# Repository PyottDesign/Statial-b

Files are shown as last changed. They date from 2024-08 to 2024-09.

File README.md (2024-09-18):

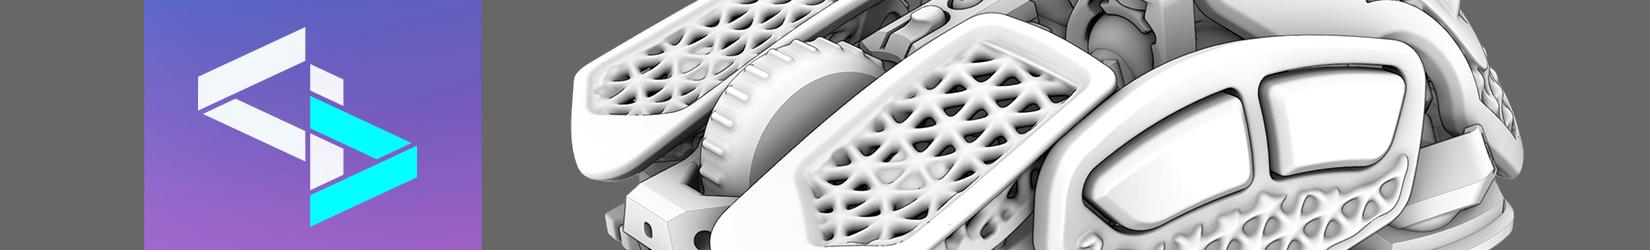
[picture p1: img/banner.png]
Statial.b Title Banner


# Statial.b Adjustable Mouse
_Modern grip styles have grown out of players adapting to standardized mouse shapes.<br/>
The Statial.b lets new mouse shapes grow from grip styles._

The Statial.b is an open source DIY mouse design. This concept has adjustable surfaces that can be moved and locked in position to create a wide range of ergonomics for any grip style. Files for ambidextrous builds are included in the STL.zip "extras" folder.

Knowledge of 3D printing, basic electronics & soldering skills as well as the ability to upload the supplied code to an Arduino are needed for this build. The design is based around a 16,000 DPI optical sensor in the [PMW3389](https://www.tindie.com/products/citizenjoe/pmw3389-motion-sensor/) and driven by an Arduino compatible [Pro Micro](https://deskthority.net/wiki/Arduino_Pro_Micro) controller.

This is a fairly complex project. I tried to cover all the assembly details in the in the [instructions PDF](statial-b_instructions_v01-00.pdf) and on the [YouTube instructions](https://youtu.be/HTKbrcy7GT0), but some problem solving skills are still going to be required.

The finished design is a functioning prototype that requires a lot of adjusting to get it dialed in and is more fragile than a normal commercially produced product. It’s also a heavy mouse weighing up to a hefty 130 grams (depending on components used). All that said, it works great and is super fun to use. There’s really nothing else like it out there if you’re looking to explore mouse ergonomics.

All 3D printed parts need to be made in a “Tough” or “ABS like” resin material. Resin print color is up to you.<br/> ***This project requires resin printed parts. 
It (probably) won't work if parts are 3D printed with an FDM printer.***

Current cost estimate is around $200 for the build materials (that's in 2024 US dollar bucks, not including tools). This is just a rough guess so you have an idea of what you’re getting into.

Please check [Statial.b Youtube build](https://youtu.be/HTKbrcy7GT0) and the [Statial.b Instructions PDF](statial-b_instructions_v01-00.pdf) for more info on this project.

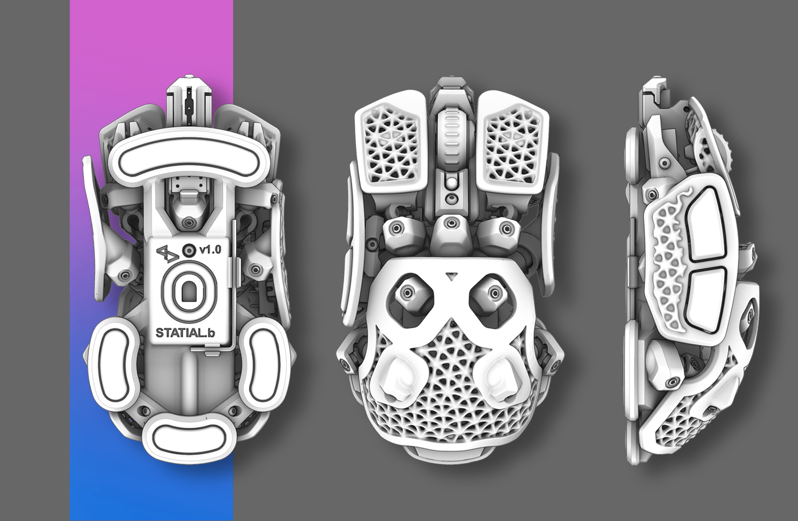
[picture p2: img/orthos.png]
Statial.b Orthos

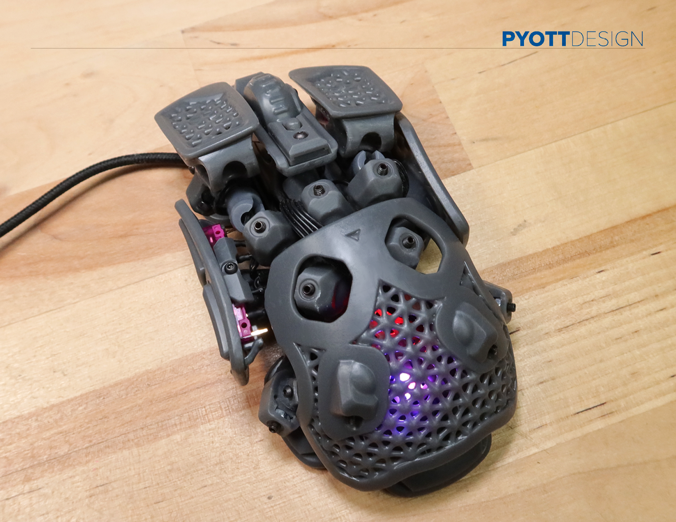
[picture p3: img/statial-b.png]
Statial.b

<br/><br/>

# Code Background
* The Statial-b Arduino Sketch is modified from the [Ben Makes Everything PMW3389 Mouse](https://github.com/BenMakesEverything/PMW3389_Mouse)
* Which is based on [Dkao's Trackball Project](https://github.com/dkao/Kensington_Expert_Mouse_PMW3389_Arduino)
* That uses source code from [MrJohnk PMW3389](https://github.com/mrjohnk/PMW3389DM)
<br/><br/>

# Parts
Full BOM with source links can be found in the [Statial.b Instructions PDF](statial-b_instructions_v01-00.pdf).

* ~170 mL of [Tough](https://formlabs.com/store/materials/tough-2000-resin/) or [ABS Like](https://store.anycubic.com/products/abs-like-resin-pro-2) resin
* [PMW3389 Optical Sensor](https://www.tindie.com/products/citizenjoe/pmw3389-motion-sensor/)
* [Pro Micro (5 Volt/16 MHz)](https://deskthority.net/wiki/Arduino_Pro_Micro)
* [Custom Bridge Board & Middle Routing Board PCB](https://jlcpcb.com/?from=PyottDesign)
* M2 button head screws & M2.5 set screws
* M2 and M2.5 nuts
* 1/8" diameter aluminum tube stock
* Mouse Glides for Logitech G-Pro
* 2.0mm pitch PH type end connectors & right angle through hole board connectors
* (5) Mouse switches
* Push button momentary switch, 6mm x 6mm x 4.5mm
* 2.54mm headers, surface mount gull wing, cut to length
* [TTC Rotary Encoder](https://a.co/d/5zIg8kU)
* [NeoPixel 5050 RGB LED](https://www.adafruit.com/product/1655)
* ~6' Micro USB cable or Mouse cable w/ micro USB port connector component 
* 28 Ga. 6 conductor silicone ribbon wire (or similar)
* Soldering Iron, Multi-meter, [PH Crimping tool](https://a.co/d/hdylA0W) and other misc. tools

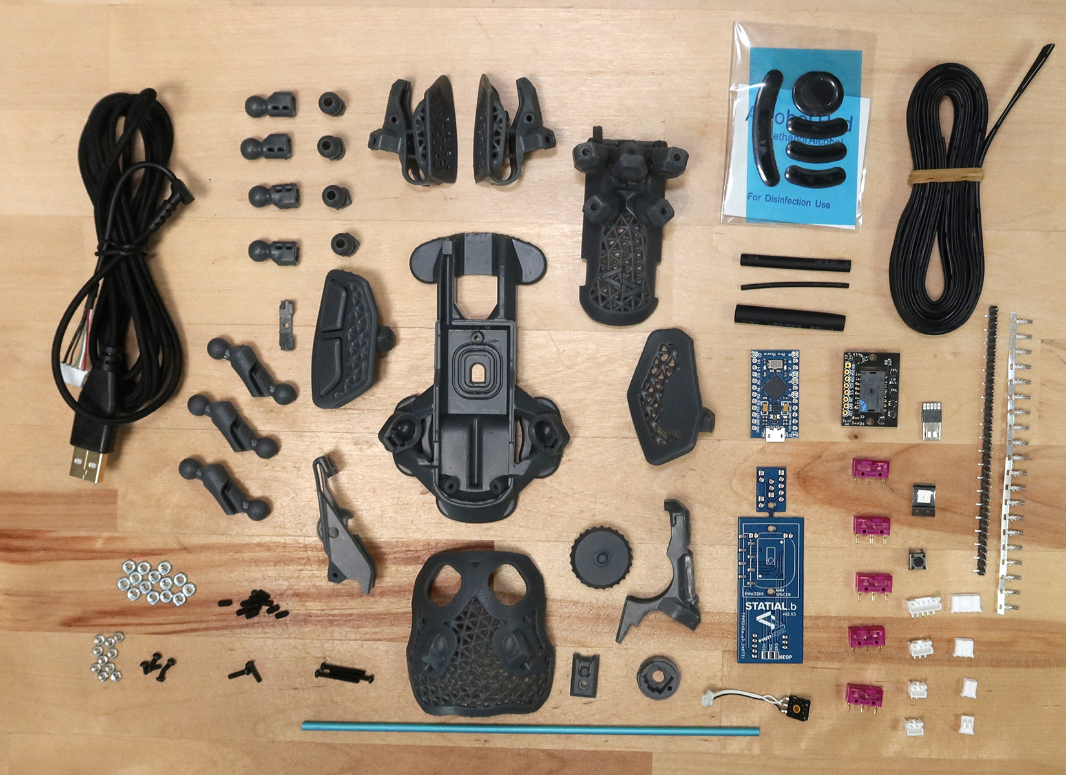
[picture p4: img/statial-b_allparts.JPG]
Statial.b All Parts

<br/><br/>

# Configurations
Below are some common grip type configurations for the Statial.b as starting points for further adjustment. Mouse ergronomics are extreamly sensitive. A 1mm or 1 degree adjustment can take an uncomfortable setup to a great one (and vice versa). When using the Statial.b, try and think about what feels right and what feels off in your grip and make micro adjstments to single surfaces only until it's dialed in. 

### VARIABLE PALM
When fully collapsed the Statial.b is slightly smaller than a normal high performance mouse. Surfaces can be moved out significantly for larger hands.
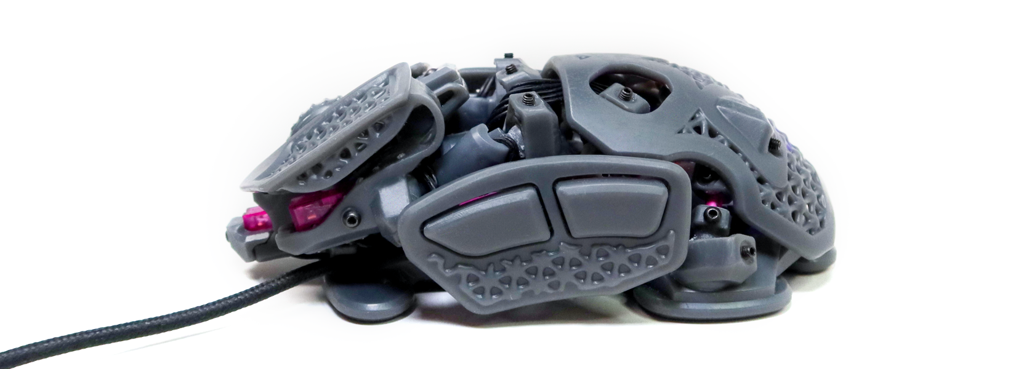
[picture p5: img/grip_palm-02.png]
Statial.b palm grip

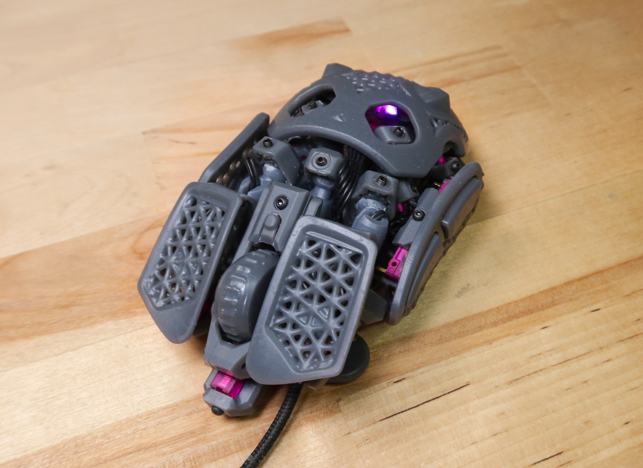
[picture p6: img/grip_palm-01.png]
Statial.b palm grip


### STUBNOSE CLAW
Unlike a normal mouse, the buttons on the Statial.b can pitch forward for different grip types. This allows claw grip users to position buttons perpendicular to the pressing motion.
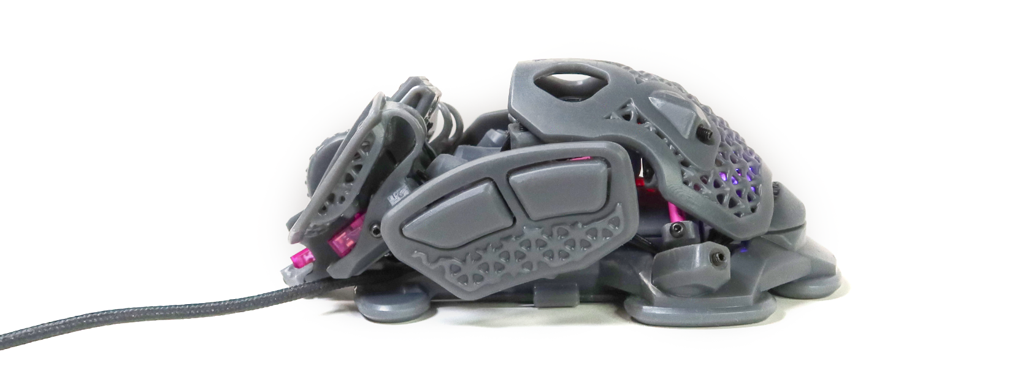
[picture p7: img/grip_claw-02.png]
Statial.b claw grip

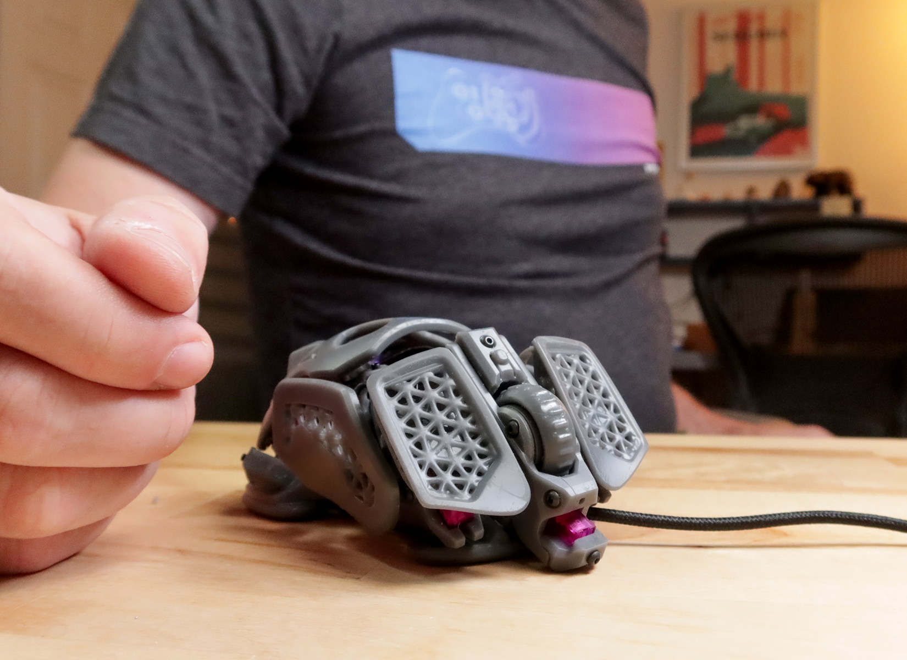
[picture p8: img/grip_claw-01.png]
Statial.b claw grip


### BACKLESS FINGER
Surfaces can be configured to experiment with alternate grip methods. For example; finger grip users can remove back surface entirely.
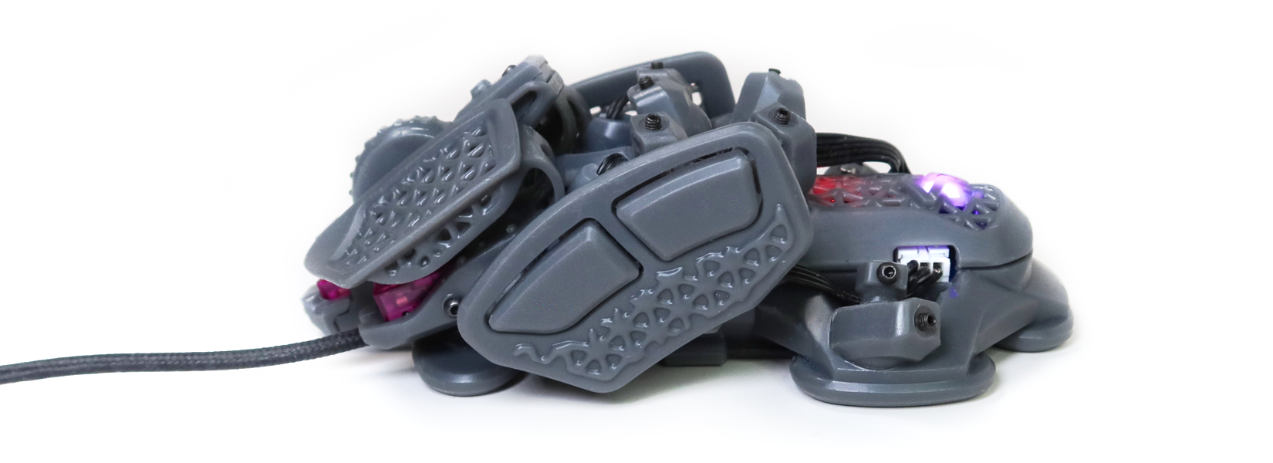
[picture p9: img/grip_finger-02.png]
Statial.b finger grip

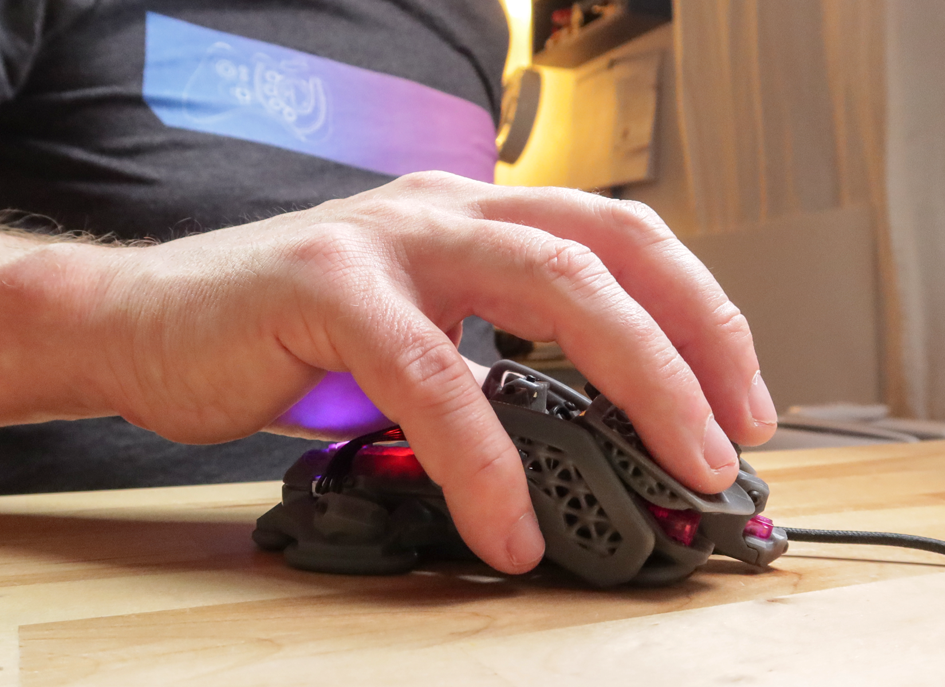
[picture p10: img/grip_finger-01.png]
Statial.b finger grip


### ERGO VERTICAL
Surfaces can be configured to +40° angle to mimic the fit of a vertical mouse. Fixed ends of rear surface arms can be extended or longer sections of tube can be cut for even steeper angles. 
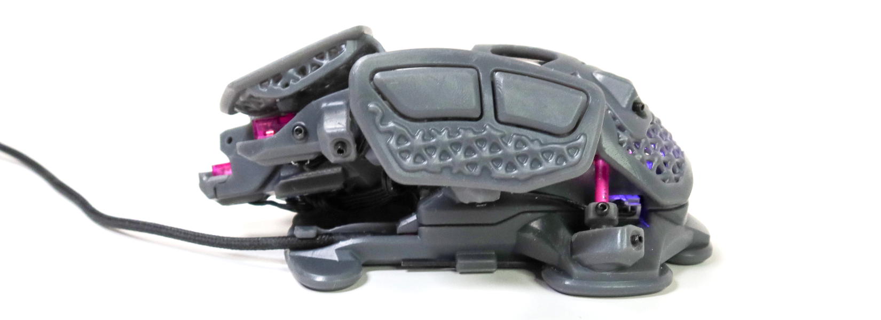
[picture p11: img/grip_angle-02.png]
Statial.b angle grip

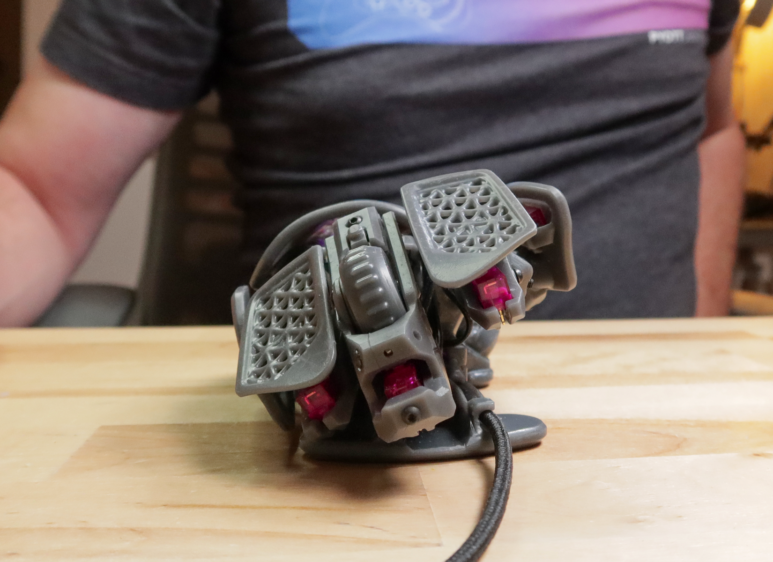
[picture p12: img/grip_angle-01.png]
Statial.b angle grip

<br/><br/>

# Instructions
For complete instructions, please download the [Statial.b Instructions PDF](https://github.com/PyottDesign/Statial-b/statial-b_instructions_v01-00.pdf).

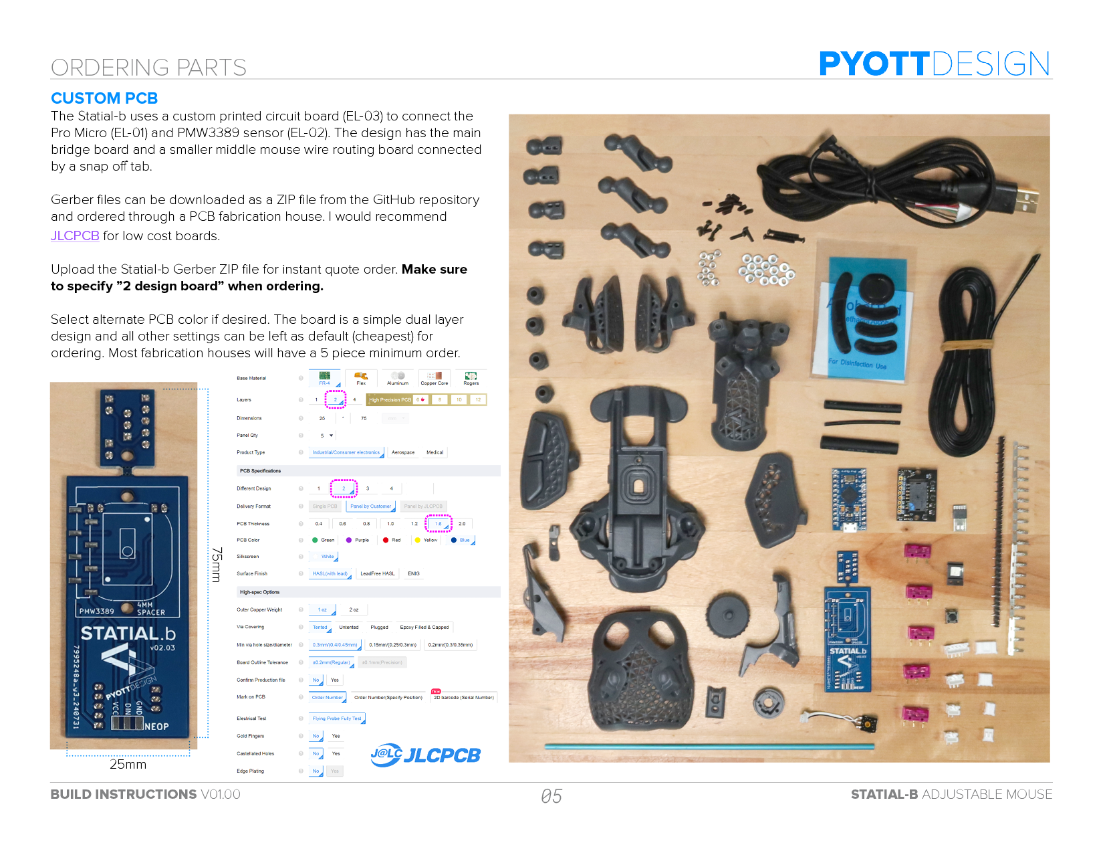
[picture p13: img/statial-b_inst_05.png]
Statial.b Instruction Manual


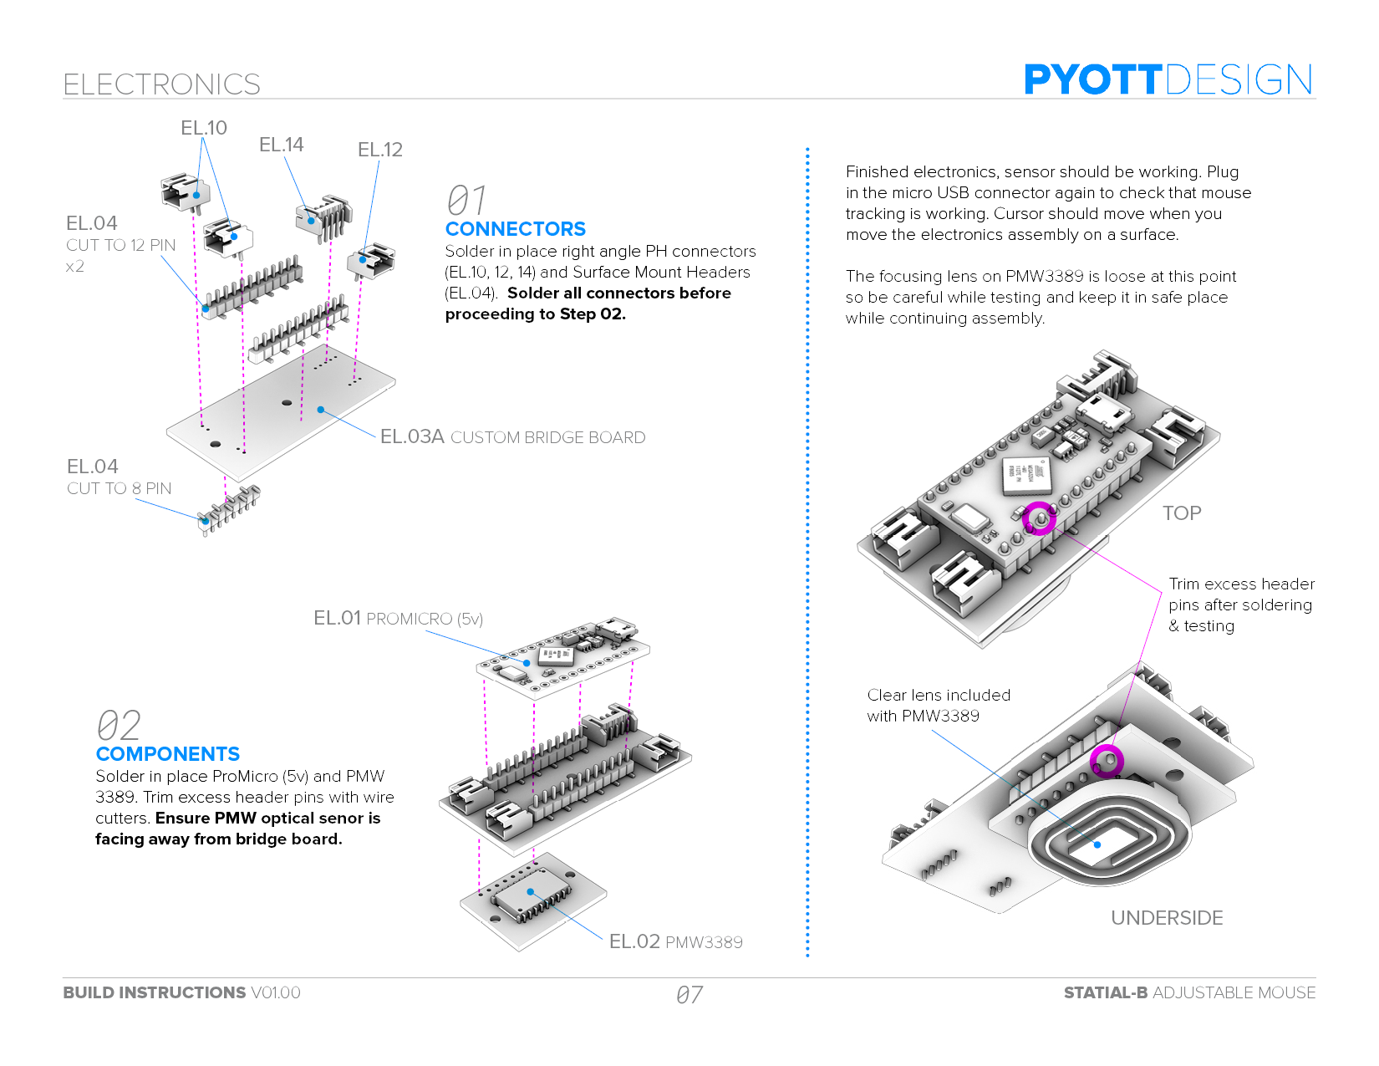
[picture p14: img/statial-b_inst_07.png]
Statial.b Instruction Manual


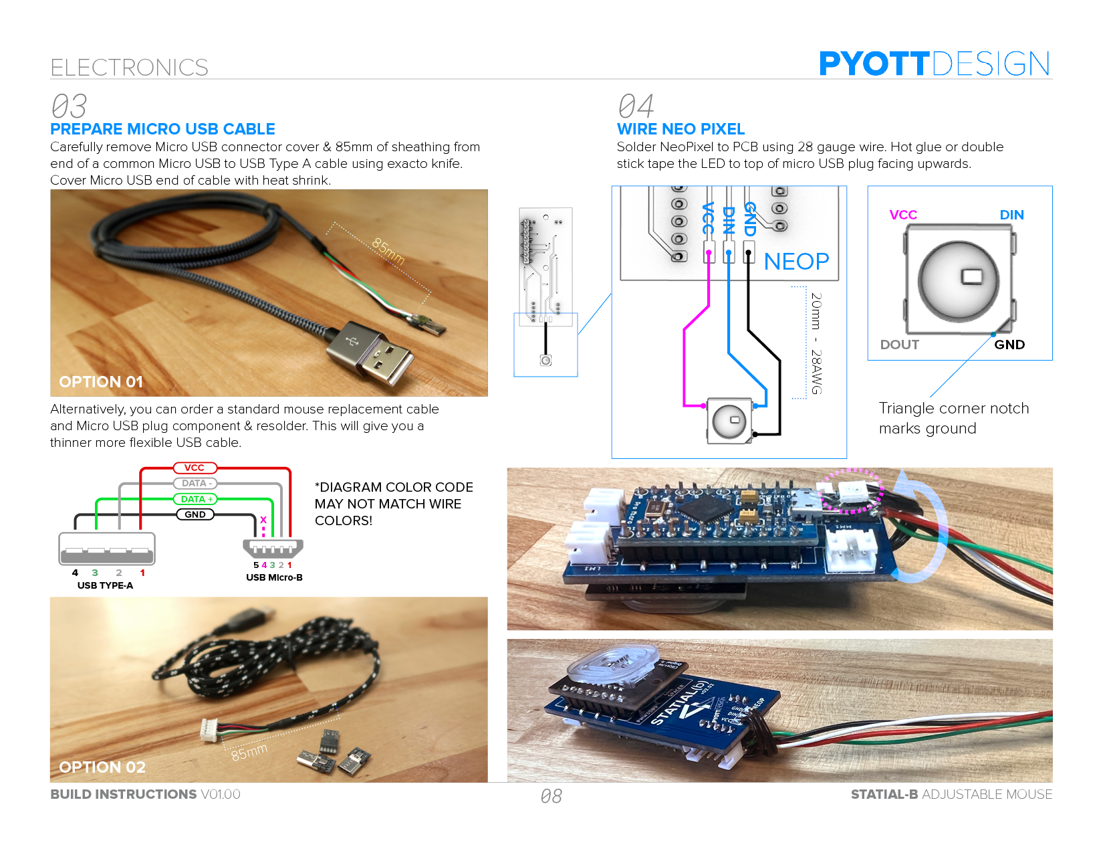
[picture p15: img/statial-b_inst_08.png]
Statial.b Instruction Manual


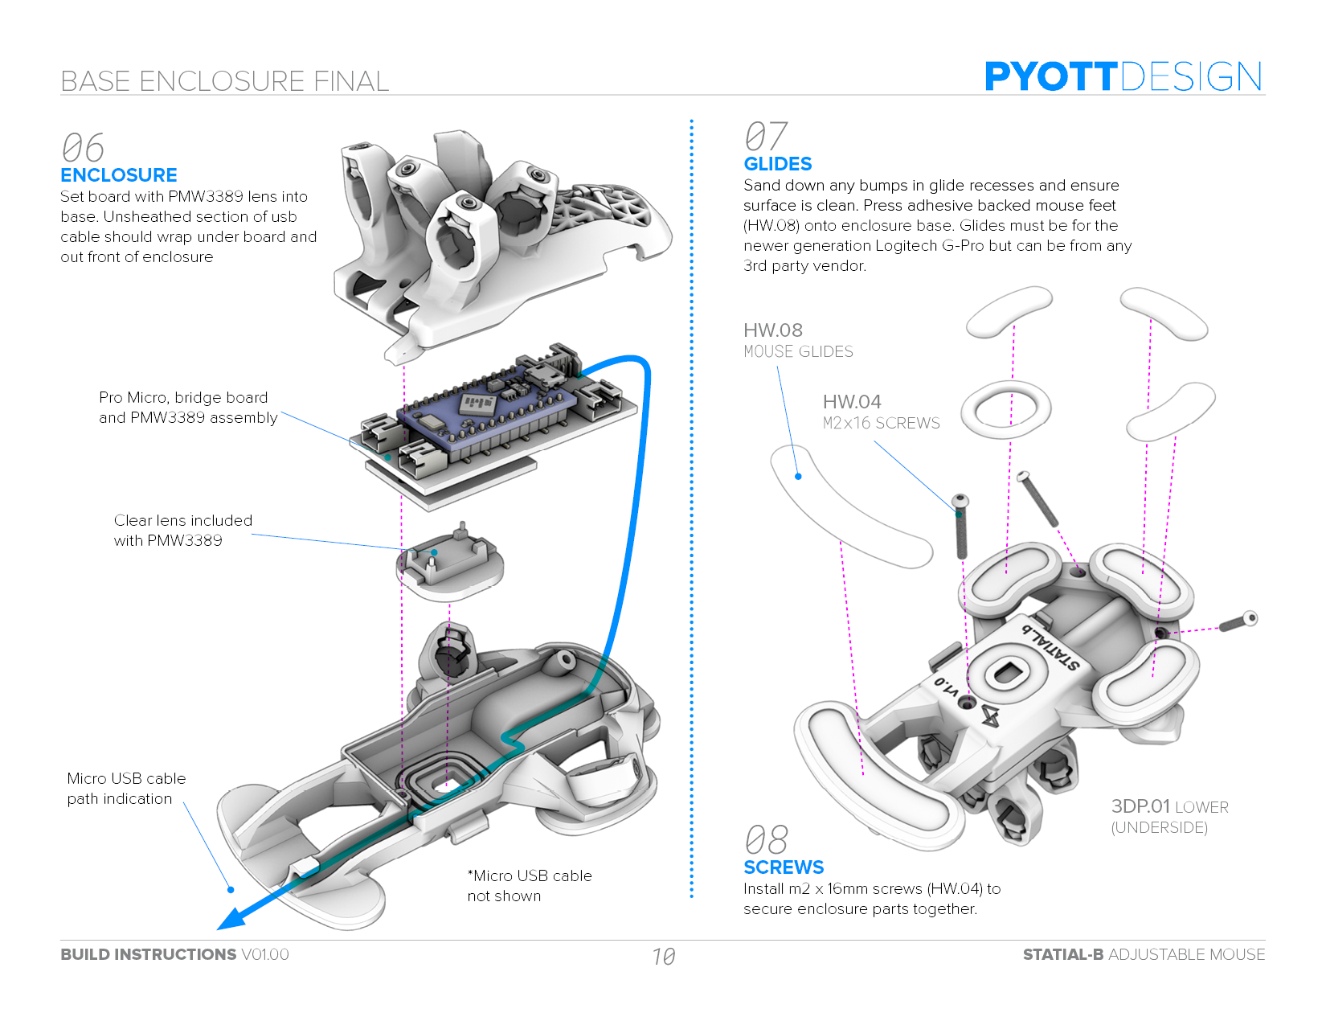
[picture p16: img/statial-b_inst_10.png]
Statial.b Instruction Manual


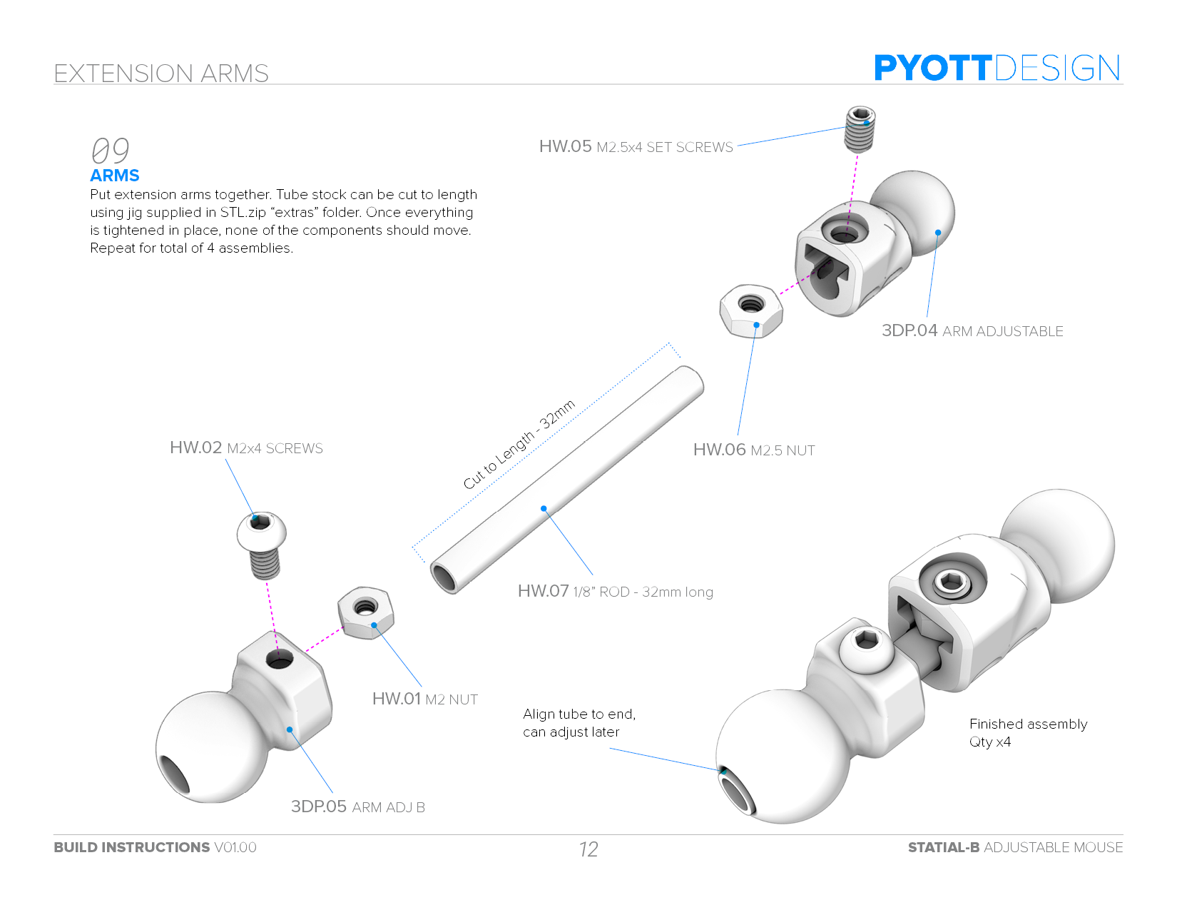
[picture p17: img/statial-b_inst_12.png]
Statial.b Instruction Manual


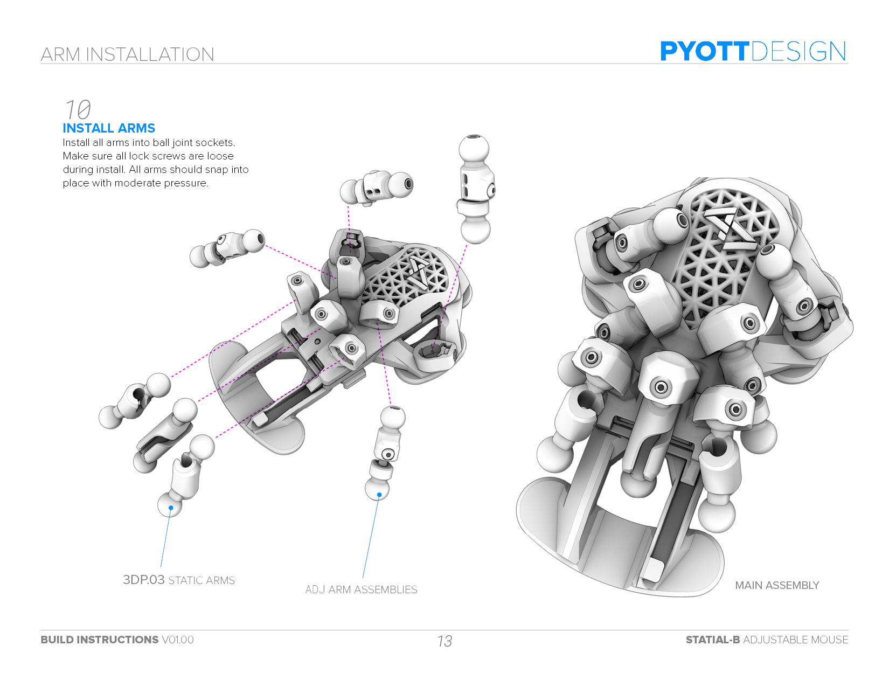
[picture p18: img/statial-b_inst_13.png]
Statial.b Instruction Manual


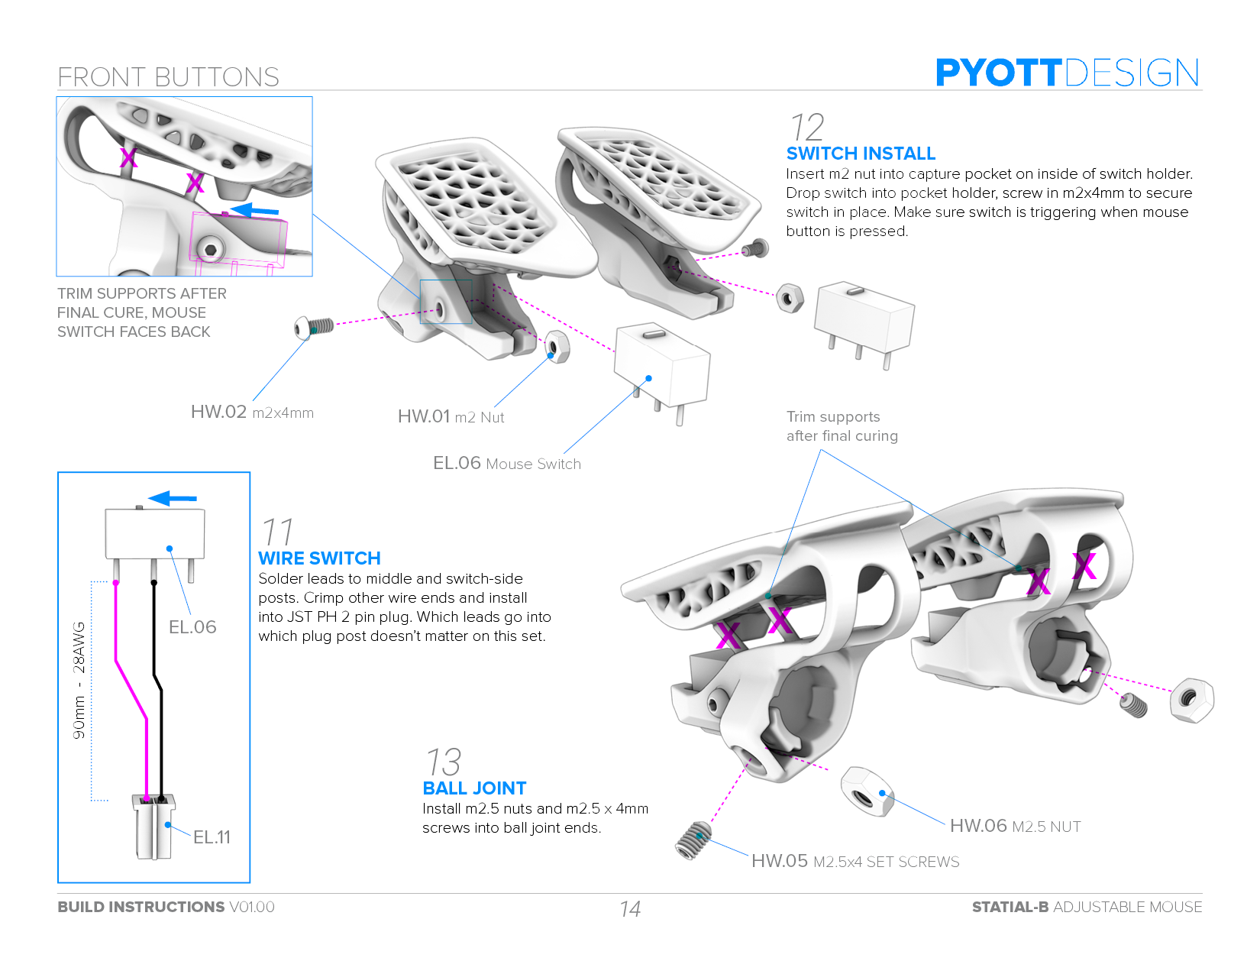
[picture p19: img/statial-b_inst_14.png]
Statial.b Instruction Manual


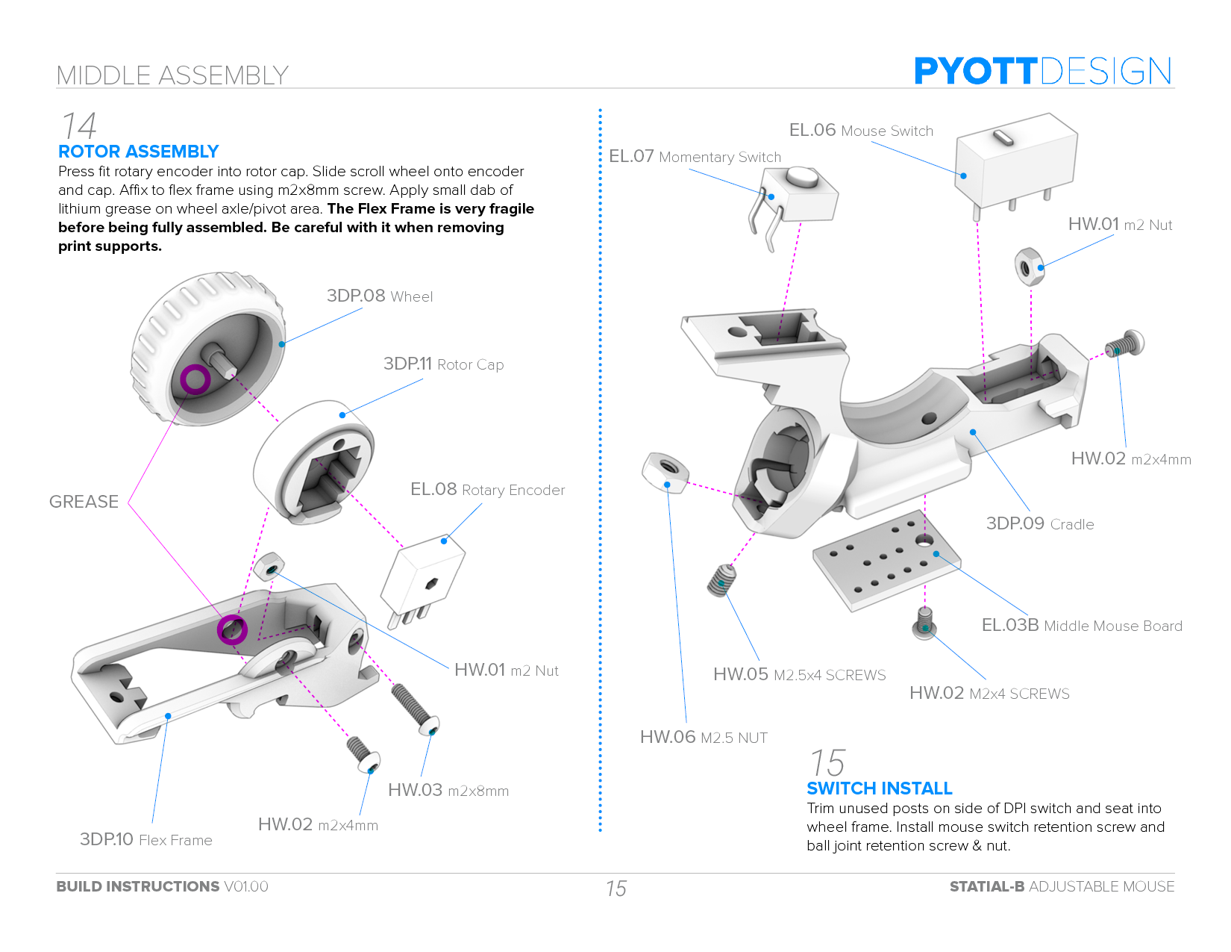
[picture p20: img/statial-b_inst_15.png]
Statial.b Instruction Manual


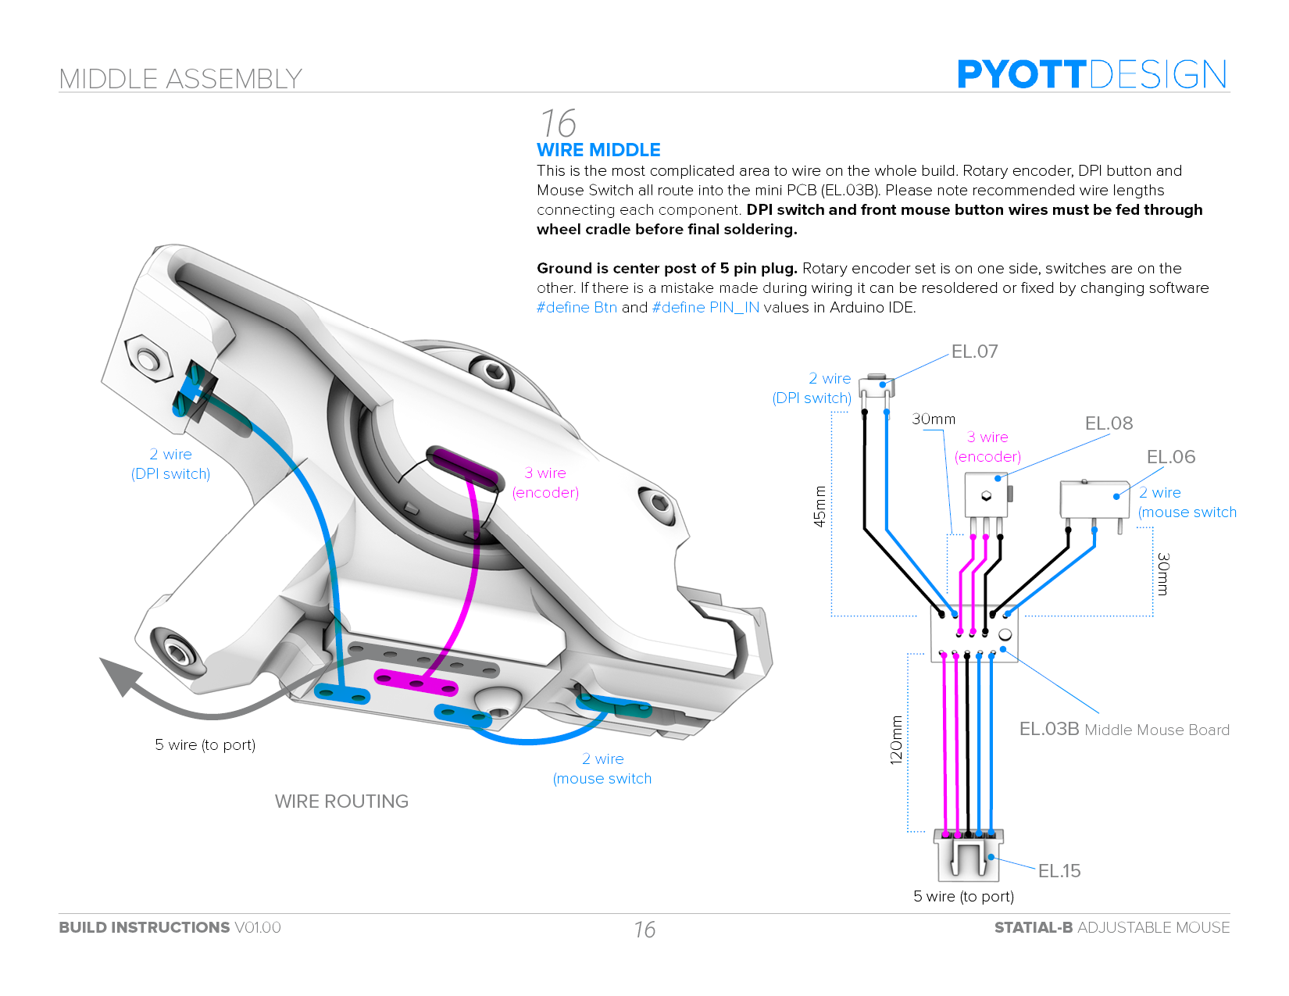
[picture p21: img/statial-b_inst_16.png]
Statial.b Instruction Manual


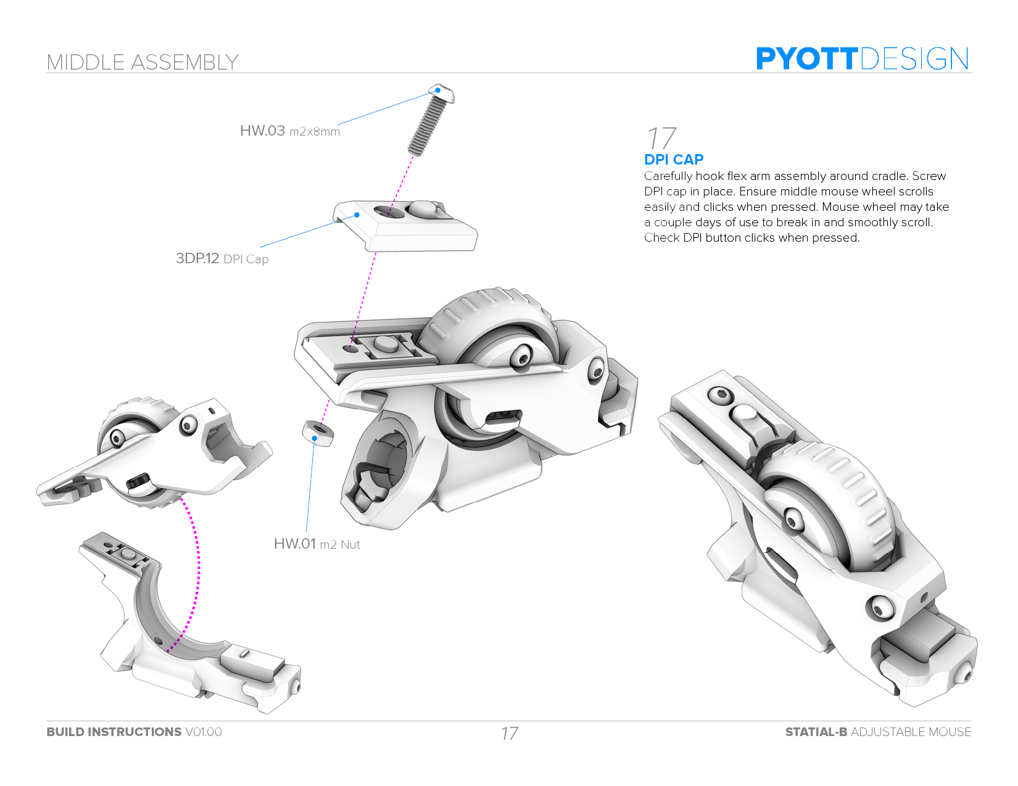
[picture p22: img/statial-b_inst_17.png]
Statial.b Instruction Manual


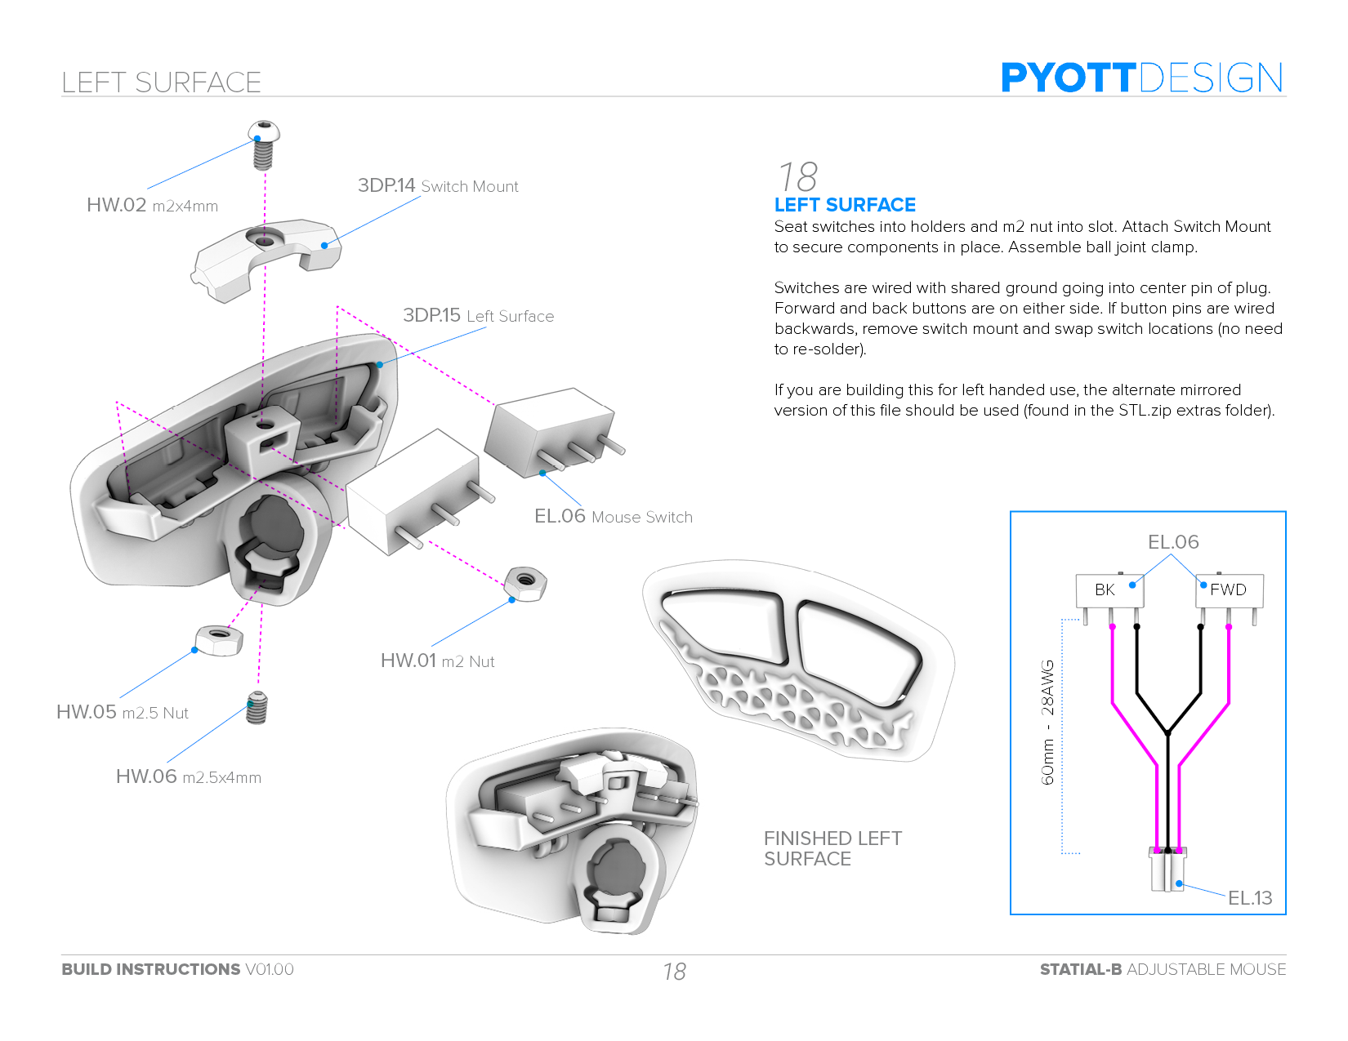
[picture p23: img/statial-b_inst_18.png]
Statial.b Instruction Manual


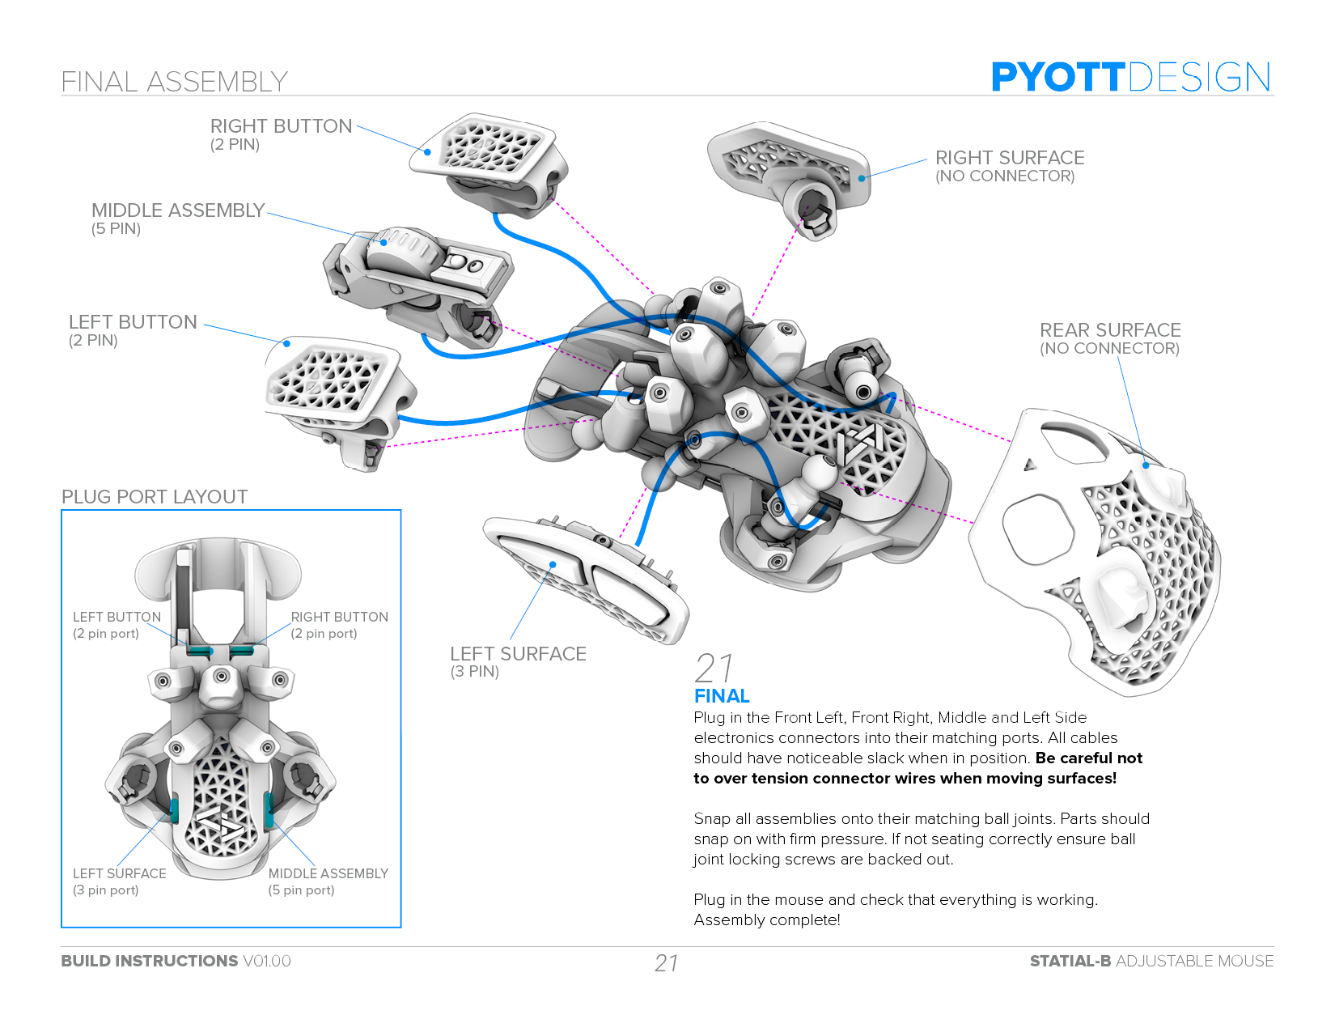
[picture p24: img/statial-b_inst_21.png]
Statial.b Instruction Manual


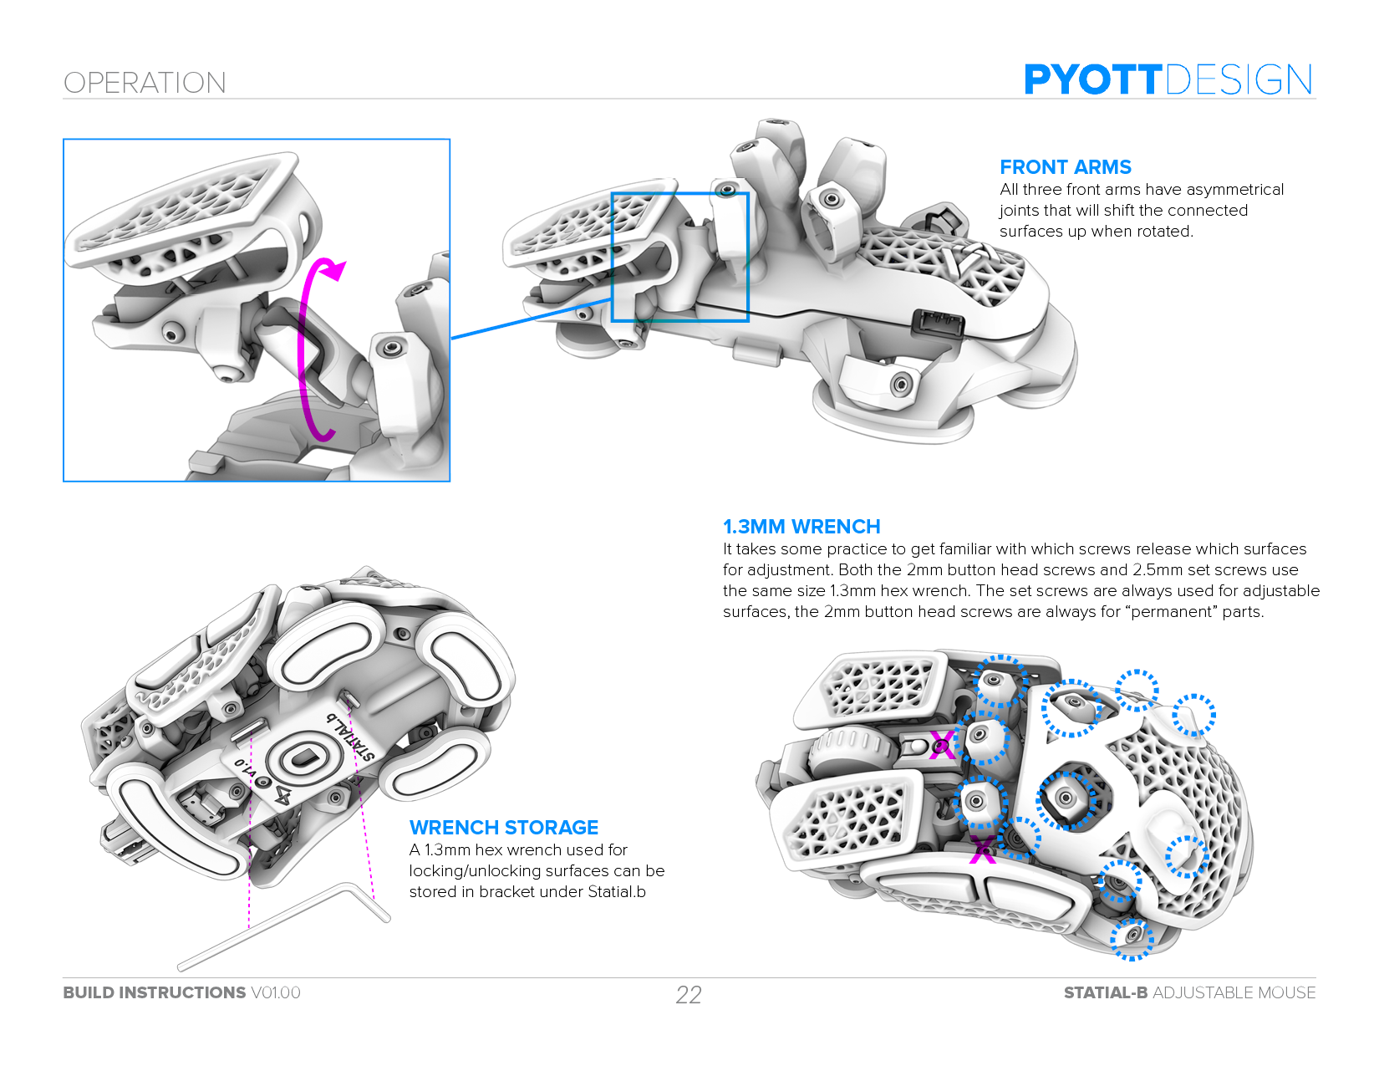
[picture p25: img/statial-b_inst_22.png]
Statial.b Instruction Manual


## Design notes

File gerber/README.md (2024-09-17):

# NOTES
Download the Statial.b Gerber file by selecting the Statial-b_v02-03_Gerber.zip link listed above.<br/>
Then select the "download raw file" icon in upper right.<br/><br/>

From there go to [JLCPCB](https://jlcpcb.com/?from=PyottDesign) and upload the Statial Gerber zip file by selecting the "add gerber file" button. The Gerber file contains both the main board and the middle mouse button sub-board connected by break away tabs so **make sure to set "Different Design" to 2.** Select your prefered board color (or leave default green). All other settings can be left as a default 2-layer 1.6mm thick.

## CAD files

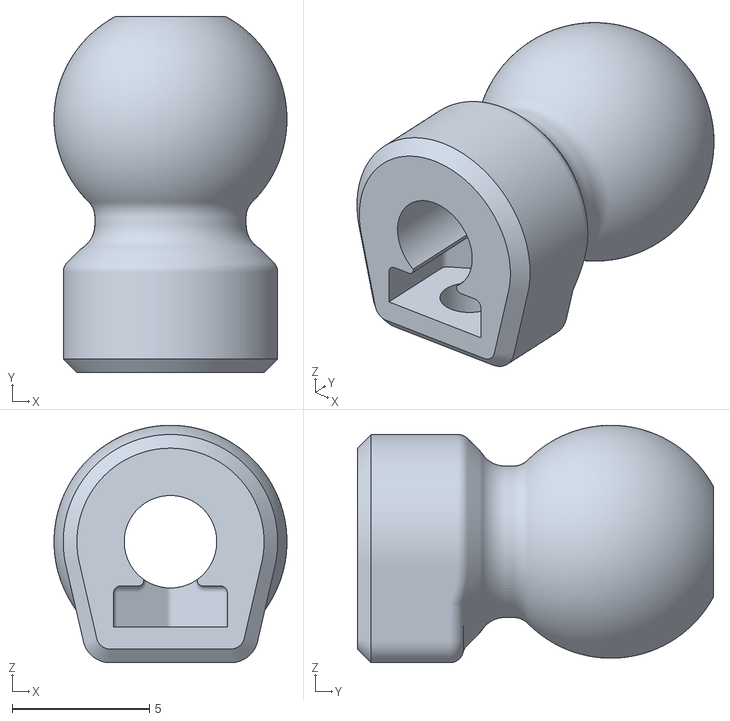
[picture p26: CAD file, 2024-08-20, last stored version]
3d_printables/stl/arm-adj-B_SBv10A01_qty-04.stl
8.50 x 13.0 x 8.66

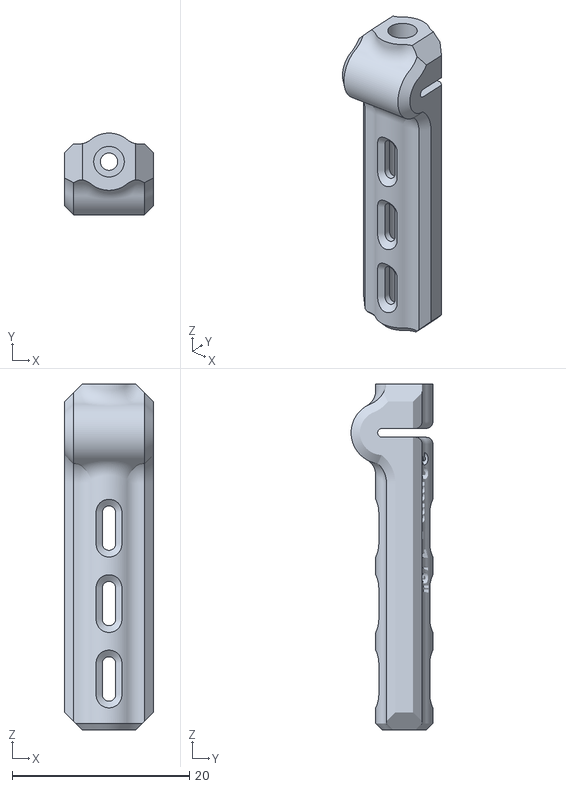
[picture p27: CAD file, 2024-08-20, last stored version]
3d_printables/stl/extras/cutting-jig_32mm.stl
10.0 x 9.22 x 39.0

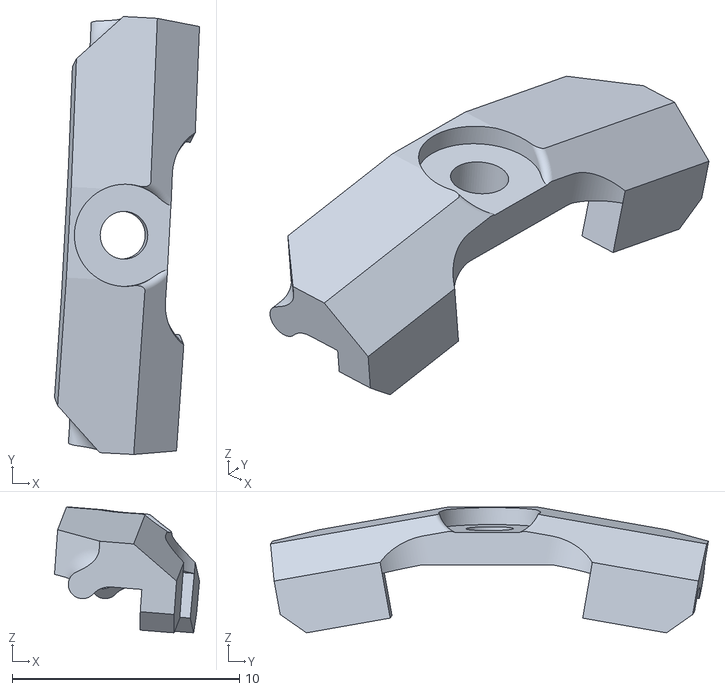
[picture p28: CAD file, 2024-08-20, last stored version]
3d_printables/stl/side-switch_SBv10A01_qty-01.stl
6.39 x 19.3 x 5.53

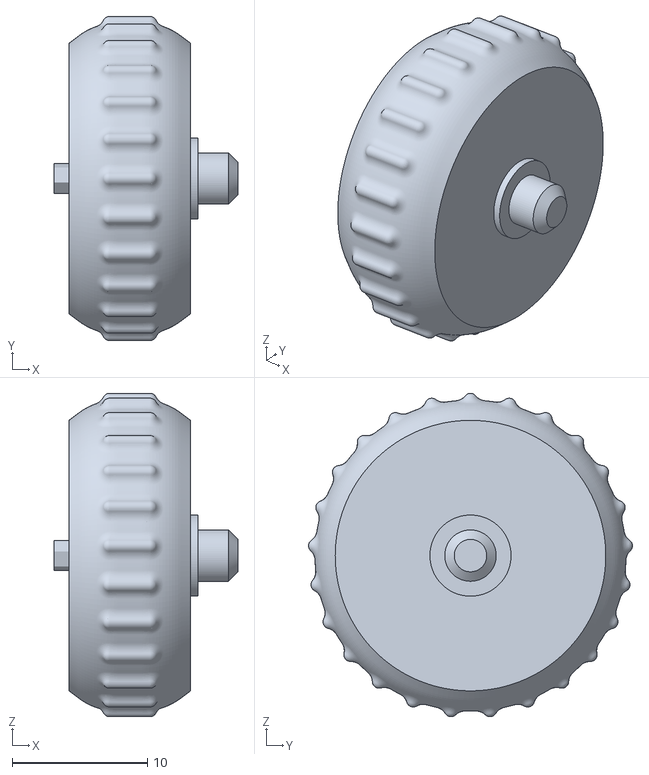
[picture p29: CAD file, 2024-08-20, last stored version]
3d_printables/stl/mid-wheel_SBv10A01_qty-01.stl
13.6 x 24.0 x 23.9

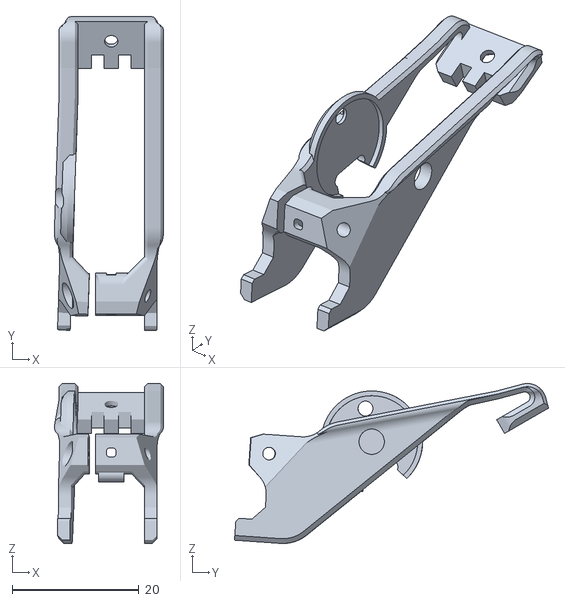
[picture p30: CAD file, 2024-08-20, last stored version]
3d_printables/stl/mid-flex_SBv10A01_qty-01.stl
17.2 x 49.5 x 25.2

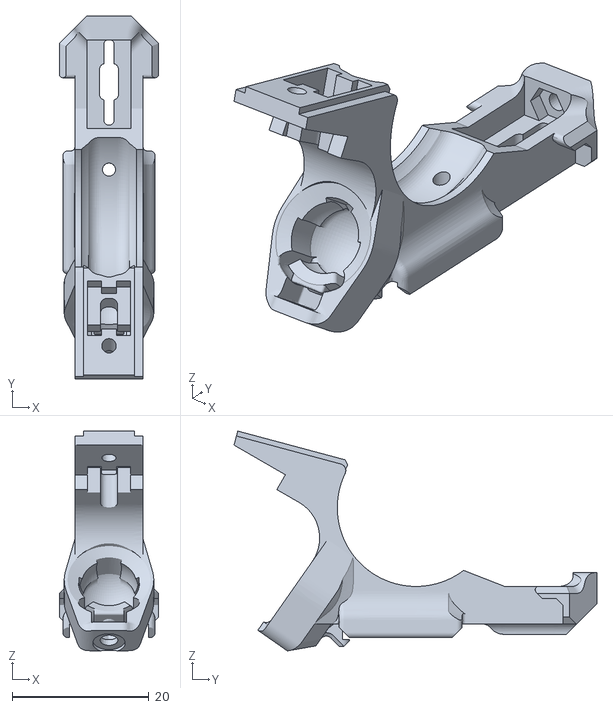
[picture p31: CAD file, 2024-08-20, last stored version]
3d_printables/stl/mid-cradle_SBv10A01_qty-01.stl
14.5 x 53.1 x 32.1

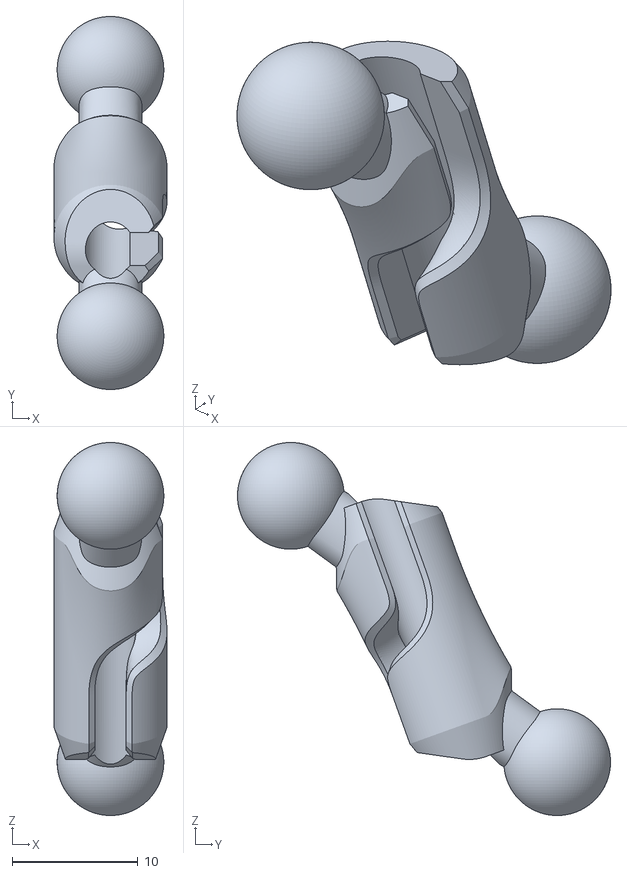
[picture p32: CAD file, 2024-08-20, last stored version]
3d_printables/stl/arm-static_SBv10A01_qty-03.stl
9.00 x 29.7 x 29.7

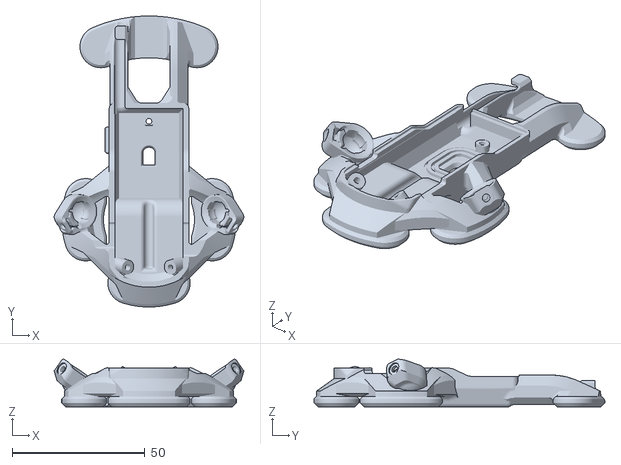
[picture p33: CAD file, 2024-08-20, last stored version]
3d_printables/stl/body-lower_SBv10A01_qty-01.stl
71.5 x 109.6 x 18.0

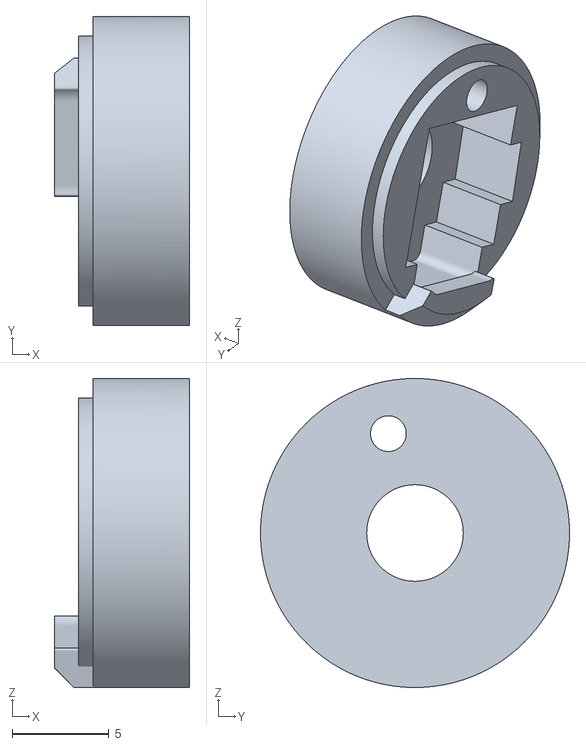
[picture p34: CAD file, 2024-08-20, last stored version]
3d_printables/stl/mid-rotor_SBv10A01_qty-01.stl
7.00 x 16.0 x 16.0

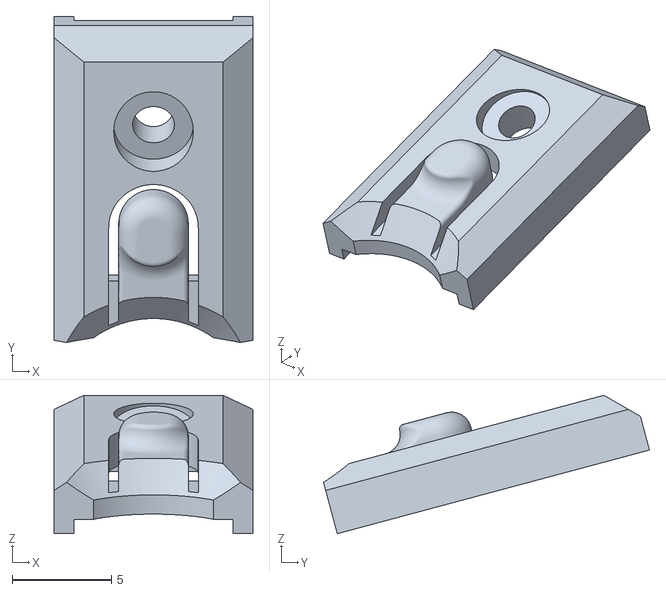
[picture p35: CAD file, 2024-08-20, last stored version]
3d_printables/stl/mid-dpi_SBv10A01_qty-01.stl
10.0 x 16.4 x 6.96

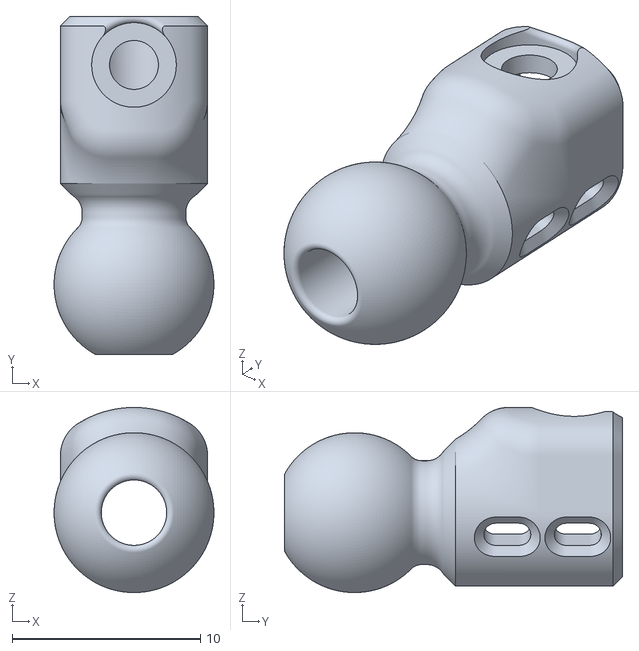
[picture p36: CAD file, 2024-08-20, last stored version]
3d_printables/stl/arm-adj-A_SBv10A01_qty-04.stl
8.50 x 18.0 x 9.84

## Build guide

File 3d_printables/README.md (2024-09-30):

# NOTES
Above STL, Lychee and Formlabs zip files are copies of most recent versions of all the 3D printable parts in various formats. Prints only tested in resin printers, FDMs probably won't work on this one. Recommend Fromlabs Tough 2000 or Anycubic ABS-Like Pro 2 resins<br/>Sunlu, Resione or Siraya equivalent are probably all good.
<br/><br/>
* Cutting jig and parts for left handed builds are in the extras folder in the STL zip file.
<br/><br/>
* All previous versions of parts are saved as individual zipped files in the /archive/.
<br/><br/>
 * The STEP.zip contains a single surface model file of the entire design for editing in CAD. This file can be ignored if you are just looking to print a copy of the Statial.b.
<br/><br/>
# CHANGELOG
* _rear_SBv10A02_qty-01.STL_ - Decreased length of rear surface for better range of motion / improves top ball socket lock screw access.

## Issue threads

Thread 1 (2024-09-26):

STEP files

lousassole, 2024-09-26:
Hello,

Is there any chance of getting the STEP and/or F3d files so I can modify this shell?
I'd like to make it fit my G903 boards, add a couple more thumb buttons, and add a thumb/pinky rest. This will all be much easier to do with the step/f3d files over the stl meshes.
I can release the modified parts to your repo, or fork it if you'd prefer.
I'd rather not re-do all the hard work you've already done with the design and engineering to make the mouse so flexible and good looking. Either way, I appreciate the work you did and hope to see more of it!
Thank you.

Closed 2024-09-30.

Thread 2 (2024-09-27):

License terms for electrical/mechanical portion of design?

bdgackle, 2024-09-27:
I see the MIT license in the code.

It would be nice to include one for the overall project -- either some CC variant to specify what's allowed, or perhaps just a clarifying statement that this is intended just for personal use if that is the case.  (Either way, thank you for putting this out there!).

I'm planning to build one of these, but would be making some changes -- would love to fork the repo publically if I come up with anything useful.  That seems to be clearly allowed for the firmware, but it's not clear what is okay for the electrical and mechanical design.

It would also be interesting to know whether people could offer kitted parts for sale based on this.  That's probably not something I'd ever get to personally, but I'd certainly love it if someone did.

PyottDesign, 2024-09-30:
Added CERN Open Hardware License (Permissive) for 3D prints & Gerber files. This should give the most flexibility for editing & repurposing the design.

Closed 2024-09-30.

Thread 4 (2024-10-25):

A little bit wrong wire on encoder

DreaM117er, 2024-10-25:
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

GND is the middle one, I step the PDF file, but the encoder can't drive.

BTW, it is crazy design, great work.

PyottDesign, 2024-10-26:
Mouse wheel rotary encoders have the common ground on one side, B in the center and A on the other side vs normal encoders with ground center.  I've wired a bunch of these up and just triple checked the wiring on the one I'm using right now, just to make sure I wasn't going crazy. The diagram in the PDF should be working a-ok.
[Kailh mouse rotary encoder details](https://www.kailhswitch.com/info/the-inruduction-of-mouse-wheel-rotary-encoder-33169856.html)
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

DreaM117er, 2024-10-27:
Oh really!? It have different problem when I  first test.

woooo, it's so great. Thank you tell me where I got wrong.

but I think the compoment HW-06 is really difficult to collect from anybody. Have you an idea to swap this one?

PyottDesign, 2024-10-27:
Huh, strange. Please let me know what you find. I want to make the instructions as clear as possible so if there is something in the wiring that was confusing or not working, please point it out.

HW-06 (1/8 inch aluminum tube stock) should be swappable with any 3mm diameter metric aluminum tube.  Something like this  [3mm OD x 0.45mm wall x 300mm](https://ksmetals.com/products/al45mm-3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) should be available internationally.

Let me know how it goes and if you have any other questions or comments. Glad you are interested in the project!

Closed 2024-10-26.

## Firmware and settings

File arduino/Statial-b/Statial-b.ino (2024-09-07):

/*For use with an Arduino Pro Micro & PMW3389 Motion Sensor.
  Complete project build files are available:

  Arduino code modified from the Ben Makes Everything Mouse, Daniel Kao Kensington Expert Mouse & Sunjun Kim PMW3360 Arduino projects: 
    https://youtu.be/qmX8vL-GbxU
    https://github.com/BenMakesEverything/PMW3389_Mouse
    https://github.com/dkao/Kensington_Expert_Mouse_PMW3389_Arduino
    https://github.com/SunjunKim/PMW3360_Arduino

  Additional PMW3389 sensor informaiton:
    https://github.com/mrjohnk/PMW3389DM
*/

#include <SPI.h>
#include <Keyboard.h>
#include <Adafruit_NeoPixel.h>
#include <RotaryEncoder.h>

//Sets mouse to use advance mode, nescessary for back/middle mouse buttons to work
#define ADVANCE_MODE

#ifdef ADVANCE_MODE
#include <AdvMouse.h>
#define MOUSE_BEGIN AdvMouse.begin()
#define MOUSE_PRESS(x) AdvMouse.press_(x)
#define MOUSE_RELEASE(x) AdvMouse.release_(x)
#else
#include <Mouse.h>
#define MOUSE_BEGIN Mouse.begin()
#define MOUSE_PRESS(x) Mouse.press(x)
#define MOUSE_RELEASE(x) Mouse.release(x)
#endif

#if defined(AVR)
#include <avr/pgmspace.h>
#else  //defined(AVR)
#include <pgmspace.h>
#endif  //defined(AVR)

#define LED_PIN 10
#define LED_COUNT 1
#define BRIGHTNESS 255  // Sets Neopixel brightness, 0-255

//Initialize Neopixel
Adafruit_NeoPixel strip(LED_COUNT, LED_PIN, NEO_GRBW + NEO_KHZ800);

// Configurations
// The default CPI value should be in between 100 -- 12000
#define CPI 2300    //Default setting when mouse is first plugged in
#define DEBOUNCE 5  //unit = ms
#define NUMCPI 7    //Number of DPI presets

#define NUMBTN 5   //Number of mouse buttons
#define NUMKEYS 1  //This is the CPI switch button

#define Btn1_Pin 1   // Left Mouse
#define Btn2_Pin 0   // Right Mouse
#define Btn3_Pin 2   // Middle Mouse
#define Btn4_Pin 19  // Forward Mouse
#define Btn5_Pin 18  // Backward Mouse
#define Btn6_Pin 7   // Cycle CPI presets

//encoder pins
#define PIN_IN1 21
#define PIN_IN2 20

//Registers
#define Product_ID 0x00
#define Revision_ID 0x01
#define Motion 0x02
#define Delta_X_L 0x03
#define Delta_X_H 0x04
#define Delta_Y_L 0x05
#define Delta_Y_H 0x06
#define SQUAL 0x07
#define Raw_Data_Sum 0x08
#define Maximum_Raw_data 0x09
#define Minimum_Raw_data 0x0A
#define Shutter_Lower 0x0B
#define Shutter_Upper 0x0C
#define Ripple_Control 0x0D
#define Resolution_L 0x0E
#define Resolution_H 0x0F
#define Config2 0x10
#define Angle_Tune 0x11
#define Frame_Capture 0x12
#define SROM_Enable 0x13
#define Run_Downshift 0x14
#define Rest1_Rate_Lower 0x15
#define Rest1_Rate_Upper 0x16
#define Rest1_Downshift 0x17
#define Rest2_Rate_Lower 0x18
#define Rest2_Rate_Upper 0x19
#define Rest2_Downshift 0x1A
#define Rest3_Rate_Lower 0x1B
#define Rest3_Rate_Upper 0x1C
#define Observation 0x24
#define Data_Out_Lower 0x25
#define Data_Out_Upper 0x26
#define SROM_ID 0x2A
#define Min_SQ_Run 0x2B
#define Raw_Data_Threshold 0x2C
#define Control2 0x2D
#define Config5_L 0x2E
#define Config5_H 0x2F
#define Power_Up_Reset 0x3A
#define Shutdown 0x3B
#define Inverse_Product_ID 0x3F
#define LiftCutoff_Cal3 0x41
#define Angle_Snap 0x42
#define LiftCutoff_Cal1 0x4A
#define Motion_Burst 0x50
#define SROM_Load_Burst 0x62
#define Lift_Config 0x63
#define Raw_Data_Burst 0x64
#define LiftCutoff_Cal2 0x65
#define LiftCutoff_Cal_Timeout 0x71
#define LiftCutoff_Cal_Min_Length 0x72
#define PWM_Period_Cnt 0x73
#define PWM_Width_Cnt 0x74

RotaryEncoder* encoder = nullptr;

const int ncs = 4;    //PMW3389 "SS" pin
const int reset = 3;  //PMW3389 "MT" pin

int Btn_pins[NUMBTN] = {Btn1_Pin, Btn2_Pin, Btn3_Pin, Btn4_Pin, Btn5_Pin};
bool Btns[NUMBTN] = {false, false, false, false, false};       // button state indicator
uint8_t Btn_buffers[NUMBTN] = {0xFF, 0xFF, 0xFF, 0xFF, 0xFF};  // button debounce buffer
char Btn_keys[NUMBTN] = { MOUSE_LEFT, MOUSE_RIGHT, MOUSE_MIDDLE, MOUSE_FORWARD, MOUSE_BACK };

int Key_pins[NUMBTN] = { Btn6_Pin };  // unassigned dpi button
bool Keys[NUMBTN] = { false };
uint8_t Key_buffers[NUMBTN] = { 0xFF };
char Key_keys[NUMBTN];

//Colors that represent the CPI/DPI setting: Yellow=0, Green=1, Teal=2, Blue=3, Purple=4, Red=5, Orange=6,  
int DpiColor[NUMCPI][6] = {  { 140, 115, 0, 0 }, { 0, 255, 0, 0 }, { 0, 155, 100, 0 }, { 0, 55, 200, 0 }, { 85, 0, 170, 0 }, { 255, 0, 0, 0 }, { 200, 55, 0, 0 } };  

unsigned long Cpis[NUMCPI] = { 400, 800, 1600, 2000, 2300, 2600, 3600 };
struct CpiUpdater {
  bool target_set;
  bool updated;
  uint8_t target_cpi_index;
};

CpiUpdater CpiUpdate = { false, false, 4 };  // Default Dpi = Cpis[2]

byte initComplete = 0;
bool inBurst = false;   // in busrt mode
bool reportSQ = false;  // report surface quality
int16_t dx, dy;

unsigned long lastTS;
unsigned long lastButtonCheck = 0;
unsigned long curTime;

//Be sure to add the SROM file into this sketch via "Sketch->Add File"
extern const unsigned short firmware_length;
extern const unsigned char firmware_data[];

void setup() {
  pinMode(ncs, OUTPUT);
  pinMode(reset, INPUT_PULLUP);
  pinMode(Btn1_Pin, INPUT_PULLUP);
  pinMode(Btn2_Pin, INPUT_PULLUP);
  pinMode(Btn3_Pin, INPUT_PULLUP);
  pinMode(Btn4_Pin, INPUT_PULLUP);
  pinMode(Btn5_Pin, INPUT_PULLUP);
  pinMode(Btn6_Pin, INPUT_PULLUP);

  attachInterrupt(digitalPinToInterrupt(PIN_IN1), checkPosition, RISING);  //c had off and worked
  attachInterrupt(digitalPinToInterrupt(PIN_IN2), checkPosition, RISING);  //c had off and worked

  SPI.begin();
  SPI.setDataMode(SPI_MODE3);
  SPI.setBitOrder(MSBFIRST);

  encoder = new RotaryEncoder(PIN_IN1, PIN_IN2, RotaryEncoder::LatchMode::TWO03);

  //Neopixel code
  strip.begin();                    // INITIALIZE NeoPixel strip object (REQUIRED)
  setColor(4);                      // make sure this is set to the same # as setCPI
  strip.show();                     // Turn OFF all pixels ASAP
  strip.setBrightness(BRIGHTNESS);  // Set brightness to default val

  performStartup();

  dx = dy = 0;

  delay(1000);
  initComplete = 9;

  lastTS = micros();

  MOUSE_BEGIN;
  Keyboard.begin();
}

void adns_com_begin() {
  digitalWrite(ncs, LOW);
}

void adns_com_end() {
  digitalWrite(ncs, HIGH);
}

byte adns_read_reg(byte reg_addr) {
  adns_com_begin();

  // send adress of the register, with MSBit = 0 to indicate it's a read
  SPI.transfer(reg_addr & 0x7f);
  delayMicroseconds(35);  // tSRAD
  // read data
  byte data = SPI.transfer(0);

  delayMicroseconds(1);  //tSCLK-NCS for read operation is 120ns
  adns_com_end();
  delayMicroseconds(19);  //tSRW/tSRR (=20us) minus tSCLK-NCS

  return data;
}

void adns_write_reg(byte reg_addr, byte data) {
  adns_com_begin();

  //send adress of the register, with MSBit = 1 to indicate it's a write
  SPI.transfer(reg_addr | 0x80);
  //sent data
  SPI.transfer(data);

  delayMicroseconds(20);  //tSCLK-NCS for write operation
  adns_com_end();
  delayMicroseconds(100);  //tSWW/tSWR (=120us) minus tSCLK-NCS. Could be shortened, but is looks like a safe lower bound
}

void adns_upload_firmware() {
  // send the firmware to the chip, cf p.18 of the datasheet
  //Write 0 to Rest_En bit of Config2 register to disable Rest mode.
  adns_write_reg(Config2, 0x00);

  // write 0x1d in SROM_enable reg for initializing
  adns_write_reg(SROM_Enable, 0x1d);

  // wait for more than one frame period
  delay(10);  // assume that the frame rate is as low as 100fps... even if it should never be that low

  // write 0x18 to SROM_enable to start SROM download
  adns_write_reg(SROM_Enable, 0x18);

  // write the SROM file (=firmware data)
  adns_com_begin();
  SPI.transfer(SROM_Load_Burst | 0x80);  // write burst destination adress
  delayMicroseconds(15);

  // send all bytes of the firmware
  unsigned char c;
  for (int i = 0; i < firmware_length; i++) {
    c = (unsigned char)pgm_read_byte(firmware_data + i);
    SPI.transfer(c);
    delayMicroseconds(15);
  }

  //Read the SROM_ID register to verify the ID before any other register reads or writes.
  adns_read_reg(SROM_ID);

  //Write 0x00 (rest disable) to Config2 register for wired mouse or 0x20 for wireless mouse design.
  adns_write_reg(Config2, 0x00);

  adns_com_end();
}

void setCPI(int cpi) {
  unsigned cpival = cpi / 50;
  adns_com_begin();
  adns_write_reg(Resolution_L, (cpival & 0xFF));
  adns_write_reg(Resolution_H, ((cpival >> 8) & 0xFF));
  adns_com_end();
}

void performStartup(void) {
  // hard reset
  adns_com_end();    // ensure that the serial port is reset
  adns_com_begin();  // ensure that the serial port is reset
  adns_com_end();    // ensure that the serial port is reset

  adns_write_reg(Shutdown, 0xb6);  // Shutdown first
  delay(300);

  adns_com_begin();  // drop and raise ncs to reset spi port
  delayMicroseconds(40);
  adns_com_end();
  delayMicroseconds(40);

  adns_write_reg(Power_Up_Reset, 0x5a);  // force reset
  delay(50);                             // wait for it to reboot

  // read registers 0x02 to 0x06 (and discard the data)
  adns_read_reg(Motion);
  adns_read_reg(Delta_X_L);
  adns_read_reg(Delta_X_H);
  adns_read_reg(Delta_Y_L);
  adns_read_reg(Delta_Y_H);
  // upload the firmware
  adns_upload_firmware();
  delay(10);

  setCPI(Cpis[CpiUpdate.target_cpi_index]);
}

// Button state checkup routine
void check_button_state() {
  // runs only after initialization
  if (initComplete != 9)
    return;

  unsigned long elapsed = curTime - lastButtonCheck;

  // Update at a period of 1/8 of the DEBOUNCE time
  if (elapsed < (DEBOUNCE * 1000UL / 8))
    return;

  lastButtonCheck = curTime;
  // Debounce mouse buttons
  for (int i = 0; i < NUMBTN; i++) {
    int btn_state = digitalRead(Btn_pins[i]);
    Btn_buffers[i] = Btn_buffers[i] << 1 | btn_state;

    if (!Btns[i] && Btn_buffers[i] == 0x00)  // button press stabilized
    {
      MOUSE_PRESS(Btn_keys[i]);
      Btns[i] = true;
    } else if (Btns[i] && Btn_buffers[i] == 0xFF)  // button release stabilized
    {
      MOUSE_RELEASE(Btn_keys[i]);
      Btns[i] = false;
    }
  }

  //Debounce for KB keys
for (int k = 0; k < NUMKEYS; k++) {
    int Key_state = digitalRead(Key_pins[k]);
    Key_buffers[k] = Key_buffers[k] << 1 | Key_state;

    if (!Keys[k] && Key_buffers[k] == 0x00)  // button press stabilized
    {
      Keyboard.press(Key_keys[k]);
      Keys[k] = true;
    } else if (Keys[k] && Key_buffers[k] == 0xFF)  // button release stabilized
    {
      Keyboard.release(Key_keys[k]);
      Keys[k] = false;
    }
  }

  // CPI switcher
  if (Keys[0] == true /*&& Keys[0] == true*/) {
    if (CpiUpdate.target_set != true) {
      CpiUpdate.target_cpi_index = (CpiUpdate.target_cpi_index + 1) % NUMCPI;
      CpiUpdate.target_set = true;
      CpiUpdate.updated = false;
      setColor(CpiUpdate.target_cpi_index);
    }
  } else {
    CpiUpdate.target_set = false;
    CpiUpdate.updated = false;
  }
}

// device signature
void dispRegisters(void) {
  int oreg[7] = {
    0x00, 0x3F, 0x2A, 0x02
  };
  char* oregname[] = {
    "Product_ID", "Inverse_Product_ID", "SROM_Version", "Motion"
  };
  byte regres;

  digitalWrite(ncs, LOW);

  int rctr = 0;
  for (rctr = 0; rctr < 4; rctr++) {
    SPI.transfer(oreg[rctr]);
    delay(1);
    regres = SPI.transfer(0);
    delay(1);
  }
  digitalWrite(ncs, HIGH);
}

void loop() {
  byte burstBuffer[12];
  curTime = micros();
  unsigned long elapsed = curTime - lastTS;

  static int pos = 0;
  encoder->tick();  // just call tick() to check the state.

  int newPos = encoder->getPosition();
  if (pos != newPos) {
    int dir = (int)encoder->getDirection();
    AdvMouse.move(0, 0, dir);
    pos = newPos;
  }

  check_button_state();

  if (!inBurst) {
    adns_write_reg(Motion_Burst, 0x00);  // start burst mode
    lastTS = curTime;
    inBurst = true;
  }

  if (elapsed >= 1000)  // polling interval : more than > 0.5 ms.
  {
    adns_com_begin();
    SPI.beginTransaction(SPISettings(4000000, MSBFIRST, SPI_MODE3));

    SPI.transfer(Motion_Burst);
    delayMicroseconds(35);  // waits for tSRAD

    SPI.transfer(burstBuffer, 12);  // read burst buffer
    delayMicroseconds(1);           // tSCLK-NCS for read operation is 120ns

    SPI.endTransaction();

    int motion = (burstBuffer[0] & 0x80) > 0;
    int surface = (burstBuffer[0] & 0x08) > 0;  // 0 if on surface / 1 if off surface

    int xl = burstBuffer[2];
    int xh = burstBuffer[3];
    int yl = burstBuffer[4];
    int yh = burstBuffer[5];

    int squal = burstBuffer[6];

    int x = xh << 8 | xl;
    int y = yh << 8 | yl;

    dx = x;
    dy = y;

    adns_com_end();

    // update only if a movement is detected.
#ifdef ADVANCE_MODE
    if (AdvMouse.needSendReport() || motion) {
      AdvMouse.move(dx, dy, 0);  //these are ngative because the sensor is rotated 180 degrees from default orientation

      dx = 0;
      dy = 0;
    }
#else
    if (motion) {
      signed char mdx = constrain(dx, -127, 127);
      signed char mdy = constrain(dy, -127, 127);

      Mouse.move(-mdx, -mdy, 0);

      dx = 0;
      dy = 0;
    }
#endif
    lastTS = curTime;
  }

  // update CPI cycled from button combo
  if (CpiUpdate.target_set == true && CpiUpdate.updated == false) {
    setCPI(Cpis[CpiUpdate.target_cpi_index]);
    CpiUpdate.updated = true;
  }
}

void checkPosition() {
  encoder->tick();
}

//R,G,B,W collor set function
void setColor(int DpiSetting) {
  int Rval = DpiColor[DpiSetting][0];
  int Gval = DpiColor[DpiSetting][1];
  int Bval = DpiColor[DpiSetting][2];
  int Wval = DpiColor[DpiSetting][3];
  strip.fill(strip.Color(Rval, Gval, Bval, Wval));
  strip.setBrightness(BRIGHTNESS);
  strip.show();
  delay(10);
}

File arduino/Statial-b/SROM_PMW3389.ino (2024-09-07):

// the firmeware that is uploaded in the ADNS each time it boots

#include <SPI.h>
#if defined(AVR)
#include <avr/pgmspace.h>
#else  //defined(AVR)
#include <pgmspace.h>
#endif  //defined(AVR)

// Firmware "ORCA3_ROW_SROMxE8" 

const unsigned short firmware_length = 4094;

const unsigned char firmware_data[] PROGMEM = {
0x01, 0xe8, 0xba, 0x26, 0x0b, 0xb2, 0xbe, 0xfe, 0x7e, 0x5f, 0x3c, 0xdb, 0x15, 0xa8, 0xb3, 
0xe4, 0x2b, 0xb5, 0xe8, 0x53, 0x07, 0x6d, 0x3b, 0xd1, 0x20, 0xc2, 0x06, 0x6f, 0x3d, 0xd9, 
0x11, 0xa0, 0xc2, 0xe7, 0x2d, 0xb9, 0xd1, 0x20, 0xa3, 0xa5, 0xc8, 0xf3, 0x64, 0x4a, 0xf7, 
0x4d, 0x18, 0x93, 0xa4, 0xca, 0xf7, 0x6c, 0x5a, 0x36, 0xee, 0x5e, 0x3e, 0xfe, 0x7e, 0x7e, 
0x5f, 0x1d, 0x99, 0xb0, 0xc3, 0xe5, 0x29, 0xd3, 0x03, 0x65, 0x48, 0x12, 0x87, 0x6d, 0x58, 
0x32, 0xe6, 0x2f, 0xdc, 0x3a, 0xf2, 0x4f, 0xfd, 0x59, 0x11, 0x81, 0x61, 0x21, 0xc0, 0x02, 
0x86, 0x8e, 0x7f, 0x5d, 0x38, 0xf2, 0x47, 0x0c, 0x7b, 0x55, 0x28, 0xb3, 0xe4, 0x4a, 0x16, 
0xab, 0xbf, 0xdd, 0x38, 0xf2, 0x66, 0x4e, 0xff, 0x5d, 0x19, 0x91, 0xa0, 0xa3, 0xa5, 0xc8, 
0x12, 0xa6, 0xaf, 0xdc, 0x3a, 0xd1, 0x41, 0x60, 0x75, 0x58, 0x24, 0x92, 0xd4, 0x72, 0x6c, 
0xe0, 0x2f, 0xfd, 0x23, 0x8d, 0x1c, 0x5b, 0xb2, 0x97, 0x36, 0x3d, 0x0b, 0xa2, 0x49, 0xb1, 
0x58, 0xf2, 0x1f, 0xc0, 0xcb, 0xf8, 0x41, 0x4f, 0xcd, 0x1e, 0x6b, 0x39, 0xa7, 0x2b, 0xe9, 
0x30, 0x16, 0x83, 0xd2, 0x0e, 0x47, 0x8f, 0xe3, 0xb1, 0xdf, 0xa2, 0x15, 0xdb, 0x5d, 0x30, 
0xc5, 0x1a, 0xab, 0x31, 0x99, 0xf3, 0xfa, 0xb2, 0x86, 0x69, 0xad, 0x7a, 0xe8, 0xa7, 0x18, 
0x6a, 0xcc, 0xc8, 0x65, 0x23, 0x87, 0xa8, 0x5f, 0xf5, 0x21, 0x59, 0x75, 0x09, 0x71, 0x45, 
0x55, 0x25, 0x4b, 0xda, 0xa1, 0xc3, 0xf7, 0x41, 0xab, 0x59, 0xd9, 0x74, 0x12, 0x55, 0x5f, 
0xbc, 0xaf, 0xd9, 0xfd, 0xb0, 0x1e, 0xa3, 0x0f, 0xff, 0xde, 0x11, 0x16, 0x6a, 0xae, 0x0e, 
0xe1, 0x5d, 0x3c, 0x10, 0x43, 0x9a, 0xa1, 0x0b, 0x24, 0x8f, 0x0d, 0x7f, 0x0b, 0x5e, 0x4c, 
0x42, 0xa4, 0x84, 0x2c, 0x40, 0xd0, 0x55, 0x39, 0xe6, 0x4b, 0xf8, 0x9b, 0x2f, 0xdc, 0x28, 
0xff, 0xfa, 0xb5, 0x85, 0x19, 0xe5, 0x28, 0xa1, 0x77, 0xaa, 0x73, 0xf3, 0x03, 0xc7, 0x62, 
0xa6, 0x91, 0x18, 0xc9, 0xb0, 0xcd, 0x05, 0xdc, 0xca, 0x81, 0x26, 0x1a, 0x47, 0x40, 0xda, 
0x36, 0x7d, 0x6a, 0x53, 0xc8, 0x5a, 0x77, 0x5d, 0x19, 0xa4, 0x1b, 0x23, 0x83, 0xd0, 0xb2, 
0xaa, 0x0e, 0xbf, 0x77, 0x4e, 0x3a, 0x3b, 0x59, 0x00, 0x31, 0x0d, 0x02, 0x1b, 0x88, 0x7a, 
0xd4, 0xbd, 0x9d, 0xcc, 0x58, 0x04, 0x69, 0xf6, 0x3b, 0xca, 0x42, 0xe2, 0xfd, 0xc3, 0x3d, 
0x39, 0xc5, 0xd0, 0x71, 0xe4, 0xc8, 0xb7, 0x3e, 0x3f, 0xc8, 0xe9, 0xca, 0xc9, 0x3f, 0x04, 
0x4e, 0x1b, 0x79, 0xca, 0xa5, 0x61, 0xc2, 0xed, 0x1d, 0xa6, 0xda, 0x5a, 0xe9, 0x7f, 0x65, 
0x8c, 0xbe, 0x12, 0x6e, 0xa4, 0x5b, 0x33, 0x2f, 0x84, 0x28, 0x9c, 0x1c, 0x88, 0x2d, 0xff, 
0x07, 0xbf, 0xa6, 0xd7, 0x5a, 0x88, 0x86, 0xb0, 0x3f, 0xf6, 0x31, 0x5b, 0x11, 0x6d, 0xf5, 
0x58, 0xeb, 0x58, 0x02, 0x9e, 0xb5, 0x9a, 0xb1, 0xff, 0x25, 0x9d, 0x8b, 0x4f, 0xb6, 0x0a, 
0xf9, 0xea, 0x3e, 0x3f, 0x21, 0x09, 0x65, 0x21, 0x22, 0xfe, 0x3d, 0x4e, 0x11, 0x5b, 0x9e, 
0x5a, 0x59, 0x8b, 0xdd, 0xd8, 0xce, 0xd6, 0xd9, 0x59, 0xd2, 0x1e, 0xfd, 0xef, 0x0d, 0x1b, 
0xd9, 0x61, 0x7f, 0xd7, 0x2d, 0xad, 0x62, 0x09, 0xe5, 0x22, 0x63, 0xea, 0xc7, 0x31, 0xd9, 
0xa1, 0x38, 0x80, 0x5c, 0xa7, 0x32, 0x82, 0xec, 0x1b, 0xa2, 0x49, 0x5a, 0x06, 0xd2, 0x7c, 
0xc9, 0x96, 0x57, 0xbb, 0x17, 0x75, 0xfc, 0x7a, 0x8f, 0x0d, 0x77, 0xb5, 0x7a, 0x8e, 0x3e, 
0xf4, 0xba, 0x2f, 0x69, 0x13, 0x26, 0xd6, 0xd9, 0x21, 0x60, 0x2f, 0x21, 0x3e, 0x87, 0xee, 
0xfd, 0x87, 0x16, 0x0d, 0xc8, 0x08, 0x00, 0x25, 0x71, 0xac, 0x2c, 0x03, 0x2a, 0x37, 0x2d, 
0xb3, 0x34, 0x09, 0x91, 0xe3, 0x06, 0x2c, 0x38, 0x37, 0x95, 0x3b, 0x17, 0x7a, 0xaf, 0xac, 
0x99, 0x55, 0xab, 0x41, 0x39, 0x5f, 0x8e, 0xa6, 0x43, 0x80, 0x03, 0x88, 0x6f, 0x7d, 0xbd, 
0x5a, 0xb4, 0x2b, 0x32, 0x23, 0x5a, 0xa9, 0x31, 0x32, 0x39, 0x4c, 0x5b, 0xf4, 0x6b, 0xaf, 
0x66, 0x6f, 0x3c, 0x8e, 0x2d, 0x82, 0x97, 0x9f, 0x4a, 0x01, 0xdc, 0x99, 0x98, 0x00, 0xec, 
0x38, 0x7a, 0x79, 0x70, 0xa6, 0x85, 0xd6, 0x21, 0x63, 0x0d, 0x45, 0x9a, 0x2e, 0x5e, 0xa7, 
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
